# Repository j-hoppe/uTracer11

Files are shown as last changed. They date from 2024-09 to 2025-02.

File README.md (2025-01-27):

# uTracer11

„uTracer11“ (read: "micro-program-tracer for PDP-11") is a signal probe that is plugged into older UNIBUS PDP-11s.

The CPU state is visualized on a host PC via a graphical user interface (GUI)

It is primarily used for micro-stepping the CPU, as a function demo, repair tool, or for entertainment.

See: https://www.retrocmp.com/tools/utracer11

## Directory structure:
* common - C++ sources needed for M93X2 Arduino and GUI ... message protocol
* CSerialPort - C++ sources for RS232 interface Linux/Windows
* duktape - embedded JScript engine

* gui - main user interface, WxWidgets project Linux/Windows

* KM11.pcb - KiCad project for KM11 adapter probe

* M93X2probe.pcb - KiCad project for M93X2 probe PCB

* M93X2probe.pio - M93X2 probe Arduino firmware, PlatformI

* M93X2probe.pdp11data - PDP-11 code to be embedded into M93X2 BOOT logic

* Pdp11BusCycleDisas - source branch of UNIBUS traffic disassmebler for different PDP-11 CPUs

* pdp1134sim - case study for a micro machine based simulator, example is a 11/34 simple program loop

* resources - helper data files, scanned jpegs

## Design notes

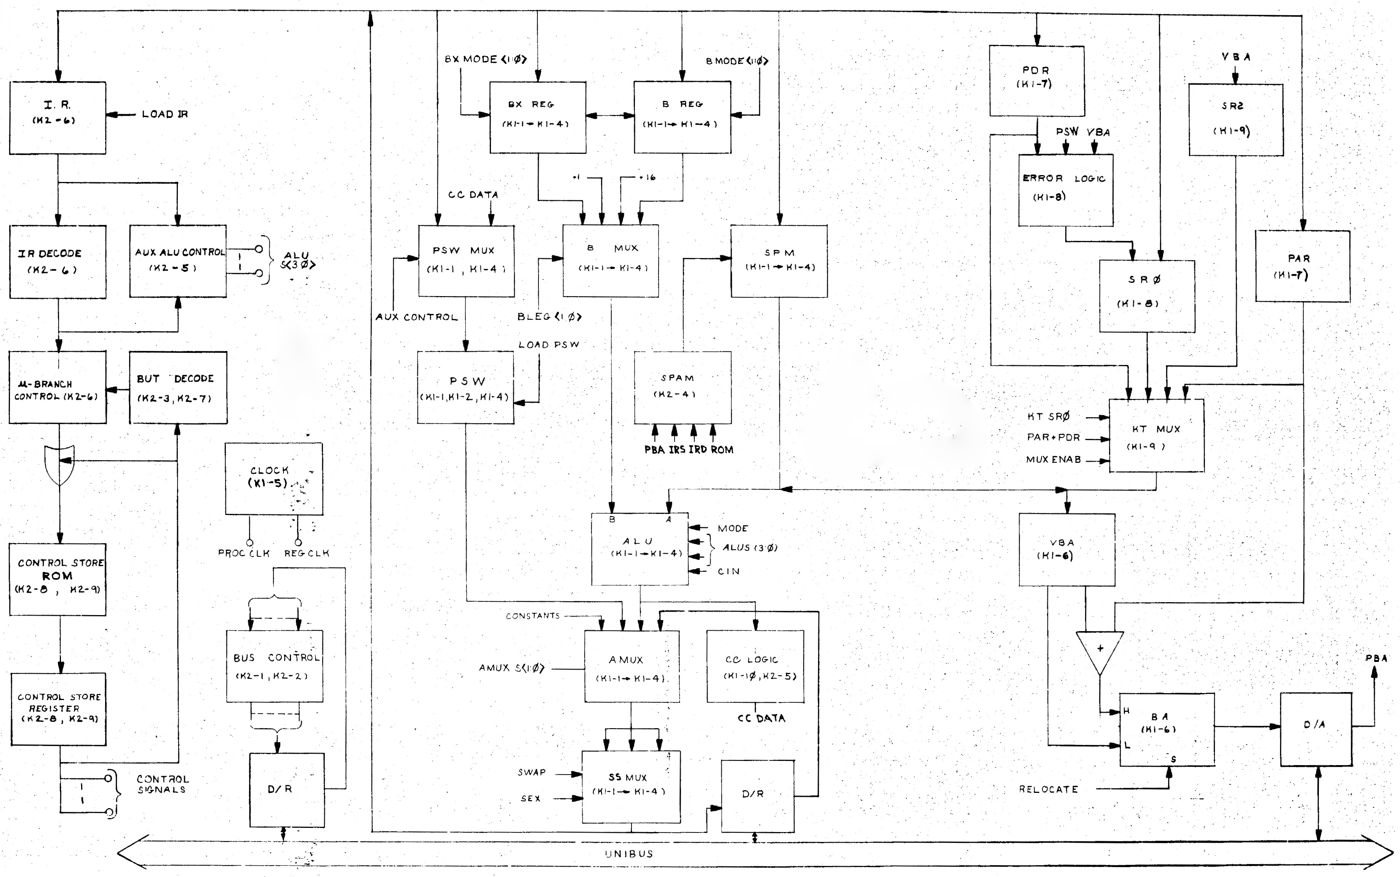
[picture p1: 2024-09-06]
resources/pdp1134/mp00082-datapath/MP00082-14.jpg

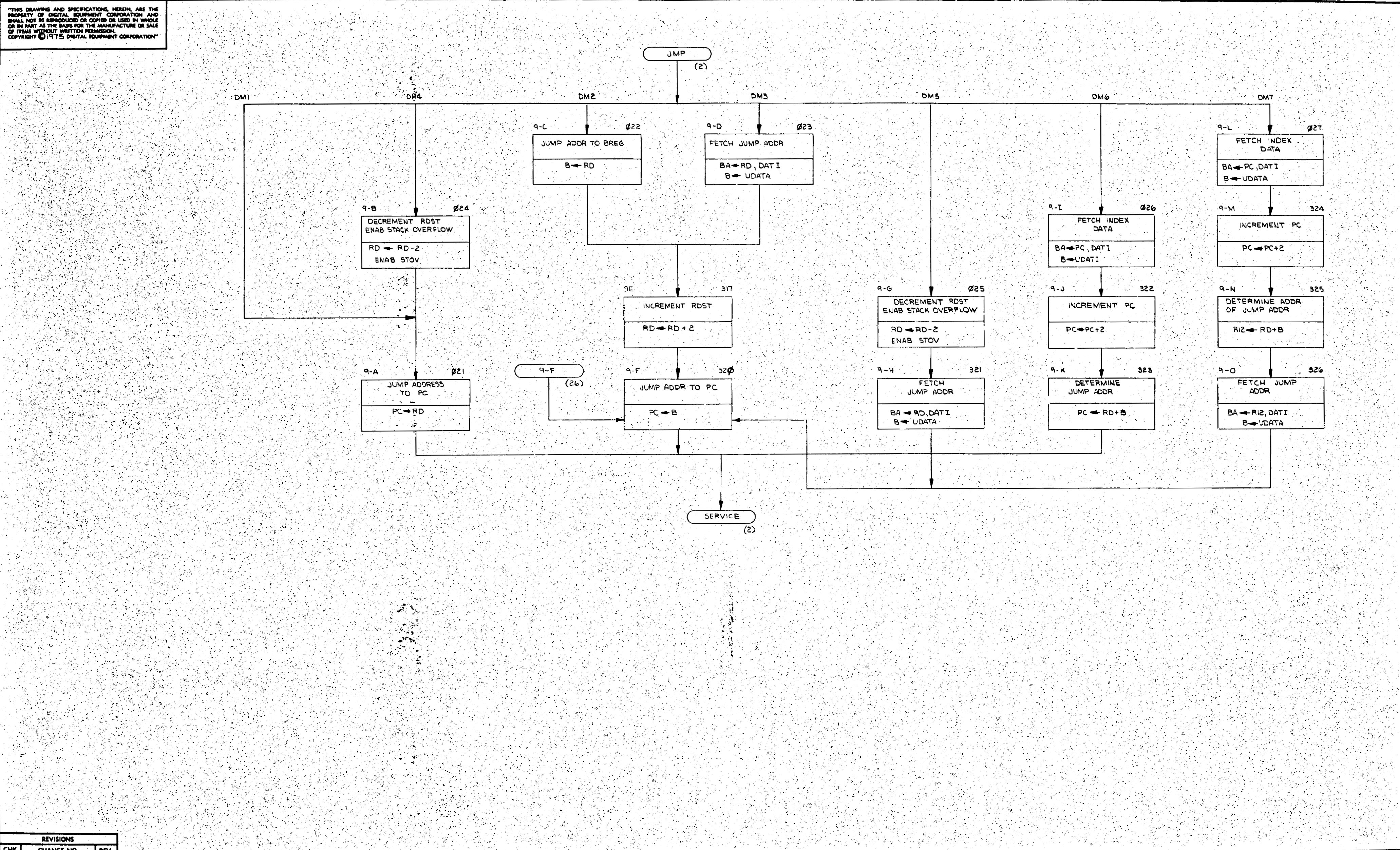
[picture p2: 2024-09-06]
resources/pdp1134/mp00082-uflow/MP00082-23.jpg

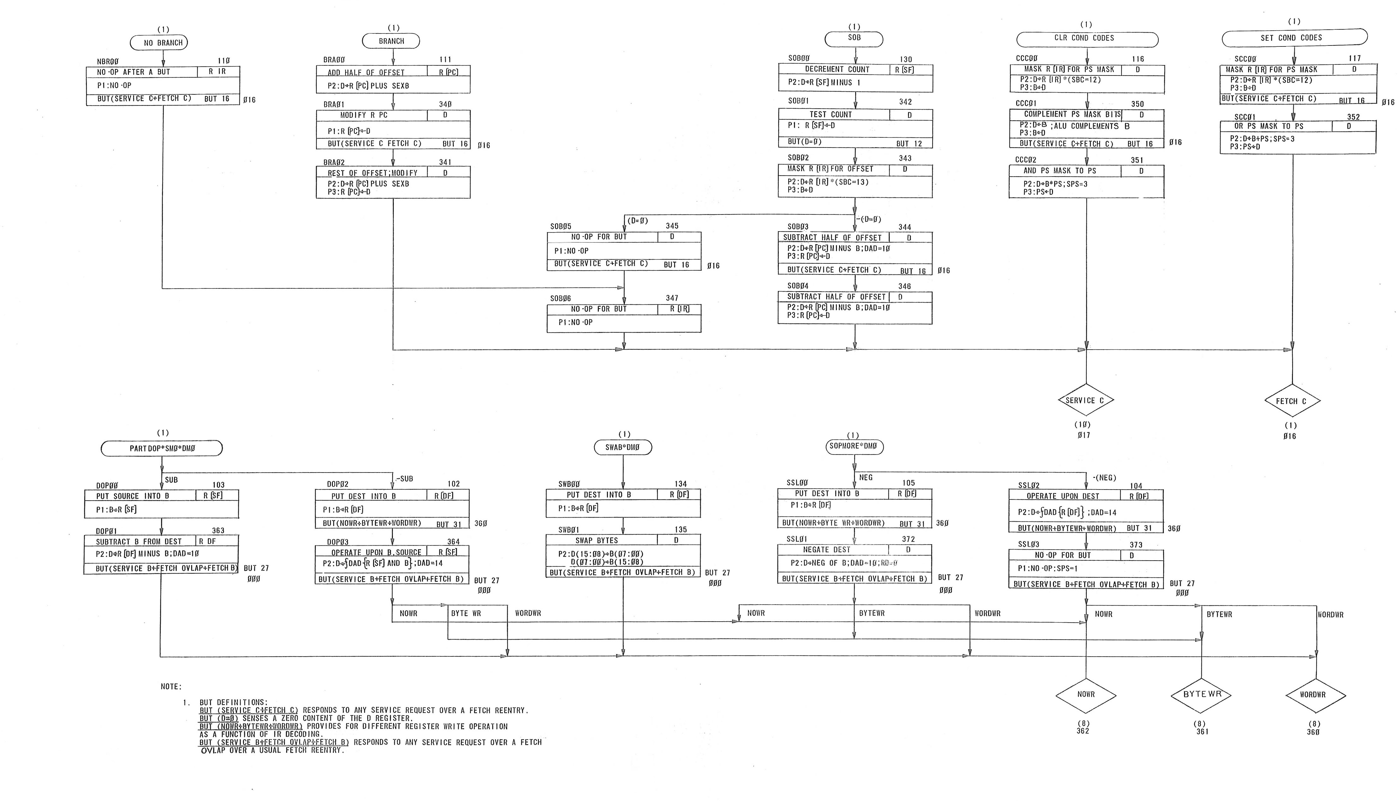
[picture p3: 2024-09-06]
resources/pdp1140/KD11-A_Processor_Flow_Diagrams/KD11-A_Processor_Flow_Diagrams-8.jpg

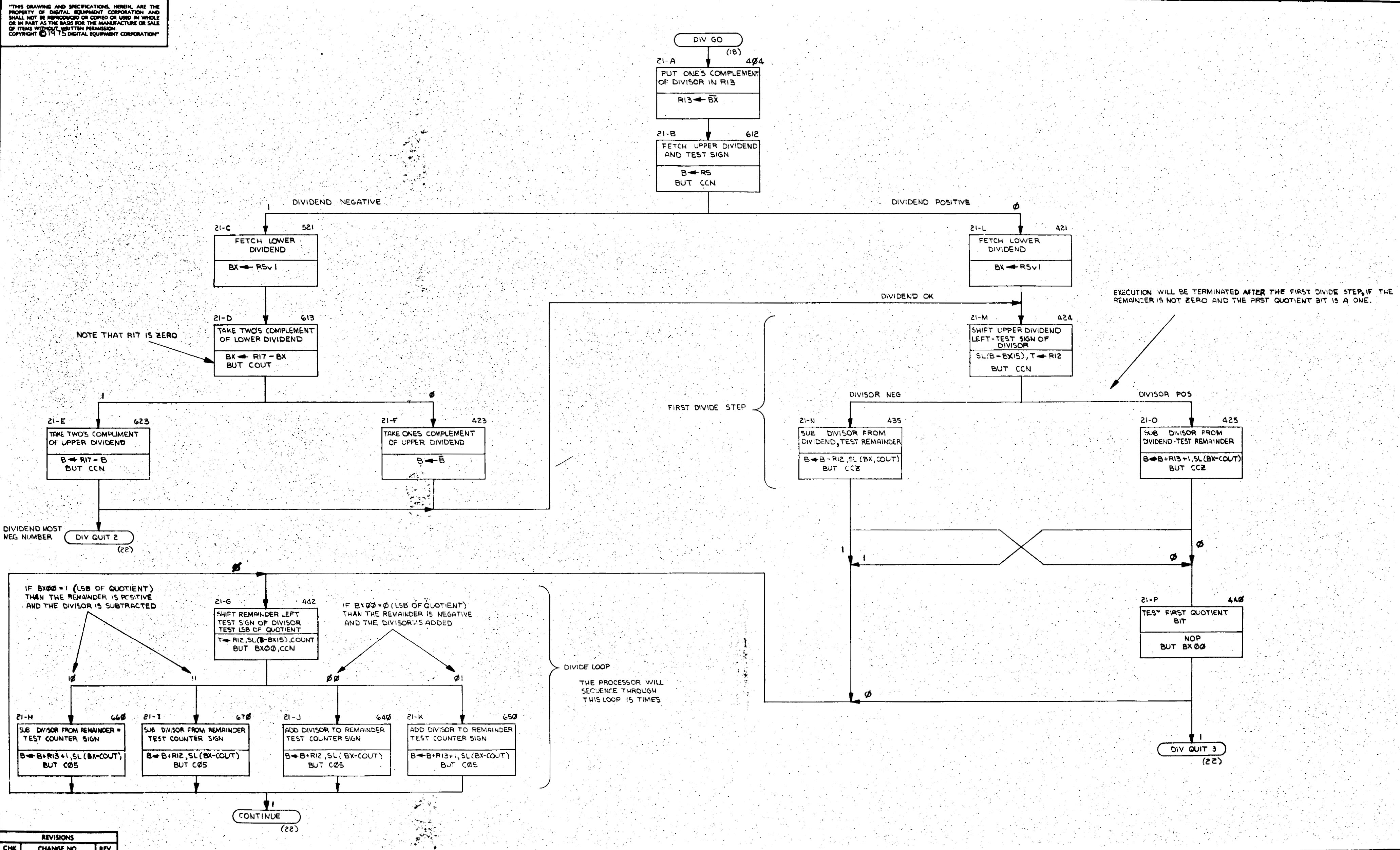
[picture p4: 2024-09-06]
resources/pdp1134/mp00082-uflow/MP00082-35.jpg

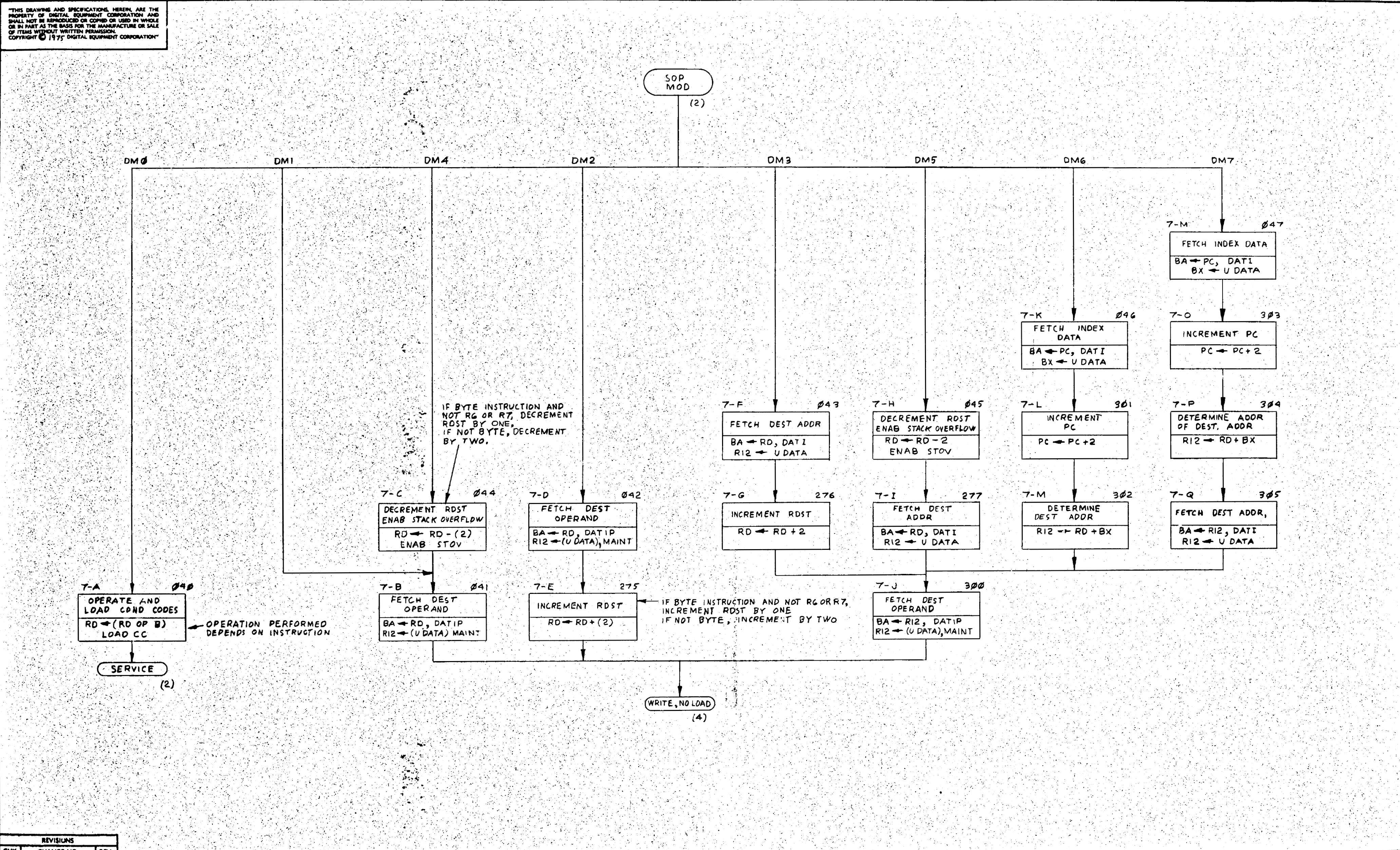
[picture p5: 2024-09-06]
resources/pdp1134/mp00082-uflow/MP00082-21.jpg

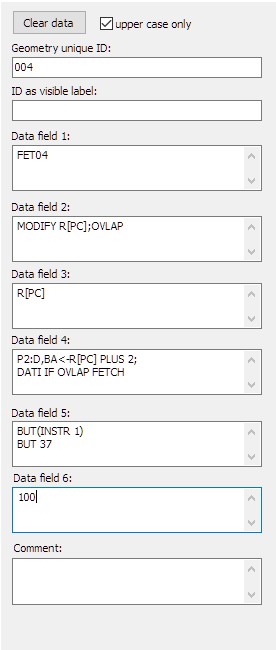
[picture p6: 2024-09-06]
resources/pdp1140/KD11-A_Processor_Flow_Diagrams/KD11-A_Processor_Flow_Diagrams-datafields-data.jpg

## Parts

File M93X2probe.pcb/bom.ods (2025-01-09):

Non-SMD parts for Diode ROM UNIBUS Base board
Count | 1
Ust | 1,19
Ref | Needed | Typ | Package | Info | Needed | At hand | Source | Nr | Preis | Anzahl | Preis total
 | 1 | Platine |  |  | 1 | 0 | jlcpcb |  | 8,00 € | 1 | 8,00 €
 | 1 | Shipping anteilig |  |  | 1 | 0 |  |  | 1,50 € | 1 | 1,50 €
 | 1 | Zoll anteilig |  |  | 1 | 0 |  |  | 0,00 € | 1 | 0,00 €
A1 | 1 | Arduino Nano Every |  |  | 1 | 0 | reichelt.de | ARD NANO EVE | 13,40 € | 1 | 13,40 €
C1-5,C7-8,C10-15,C21-36 | 29 | 100nF |  |  | 29 | 0 | reichelt.de | Z5U-5 100N | 0,08 € | 29 | 2,32 €
C6,C9 | 2 | 1nF |  |  | 2 | 0 | reichelt.de | KERKO 1,0N | 0,06 € | 2 | 0,12 € | x
C16 | 1 | 47uF |  | axial L=10, D=4.5 | 1 | 0 | reichelt.de | AX 47/16 | 0,31 € | 1 | 0,31 € | x
C17-20 | 4 | 1uF |  |  | 4 | 0 | reichelt.de | Z5U-5 1,0µ | 0,28 € | 4 | 1,12 € | x
D1,D2 | 2 | LED 3mm rot |  |  | 2 | 0 | reichelt.de | LED 3MM RT | 0,07 € | 2 | 0,14 € | x
D3-D6 | 4 | 1n4148 |  |  | 4 | 0 | reichelt.de | 1N 4148 | 0,02 € | 4 | 0,08 € | x
Jx | 2,2 | diverse pin header, 50er |  |  | 2,2 | 0 | reichelt.de | SL 1X50G 2,54 | 0,46 € | 2,2 | 1,01 € | x
J23,24 | 2 | 2x17 IDC |  | to KM11 | 2 | 0 | reichelt.de | WSL 34W | 0,32 € | 2 | 0,64 € | x
J18-22 | 5 | 2x5 IDC |  | RS232,KY11,M8266 | 5 | 0 | reichelt.de | WSL 10W | 0,13 € | 5 | 0,65 € | x
J30,31 | 2 | Flachstecker löt |  |  | 2 | 0 | reichelt.de | FS-PW-6,35 | 0,22 € | 2 | 0,44 € | x
JP1 | 1 | Jumper |  |  | 1 | 0 | reichelt.de | JUMPER 2,54 BL | 0,02 € | 1 | 0,02 €
R1-4 | 4 | 3.3K |  | I2C | 4 | 0 | reichelt.de | METALL 3,30K | 0,07 € | 4 | 0,28 € | x
R5,6 | 2 | 220 Ohm |  | LEDs | 2 | 0 | reichelt.de | METALL 220 | 0,07 € | 2 | 0,14 € | x
R7,8 | 2 | 390 Ohm |  | TERM | 2 | 0 | reichelt.de | METALL 390 | 0,07 € | 2 | 0,14 €
R9,10,12 | 3 | 1K |  | KY11 | 3 | 0 | reichelt.de | METALL 1,00K | 0,07 € | 3 | 0,21 € | x
RN1-2,RN5-6,RN9-10,RN13 | 7 | Rnet bussed 178 |  | UNIBUS terminators 178→180 | 7 | 0 | reichelt.de | SIL 9-8 180 | 0,15 € | 7 | 1,05 €
RN3-4,RN7-8,RN11-12,RN14 | 7 | Rnet bussed 383 |  | UNIBUS terminators 383→390 | 7 | 0 | reichelt.de | SIL 9-8 390 | 0,11 € | 7 | 0,77 € | x
R11 | 1 | 22k |  |  | 1 | 0 | reichelt.de | METALL 22,0K | 0,04 € | 1 | 0,04 € | x
 | 1,97 | 1x9 IC socket row precision, 64er |  |  | 1,97 | 0 | reichelt.de | SPL 64 | 1,30 € | 2 | 2,60 € | x
SW1 | 1 | Push button |  | Reset | 1 | 0 | reichelt.de | TASTER 3305 | 0,19 € | 1 | 0,19 € | x
SW2 | 1 | DIP Switch 6er Piano |  |  | 1 | 0 | reichelt.de | DP 06 | 0,31 € | 1 | 0,31 € | x
U1 | 1 | 74LS138 |  |  | 1 | 0 | reichelt.de | 74HCT 138 (https://www.reichelt.de/decoder-3-to-8-4-5--5-5-v-dil-16-74hct-138-p3318.html?&trstct=pos_0&nbc=1) | 0,63 € | 1 | 0,63 €
U2 | 1 | 74HCT30 |  |  | 1 | 0 | reichelt.de | 74LS30 | 1,10 € | 1 | 1,10 €
U3 | 1 | 8837 |  |  | 1 | 0 | ebay.de |  | 0,99 € | 1 | 0,99 €
U4 | 1 | 8881 |  |  | 1 | 0 | ebay.de |  | 0,99 € | 1 | 0,99 €
U5 | 1 | MAX232 |  |  | 1 | 0 | reichelt.de | MAX 232 DIP | 0,70 € | 1 | 0,70 €
U7 | 1 | 74LS86 |  |  | 1 | 0 | reichelt.de | 74HCT 86 | 0,67 € | 1 | 0,67 €
U6,U8-12,U15-16,U22-25 | 12 | MCP23017 |  |  | 12 | 0 | reichelt.de | MCP 23017-E/SP (https://www.reichelt.de/i-o-erweiterung-16bit-1-8-5v-seriell-i2c-dip-28-mcp-23017-e-sp-p140074.html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) | 1,80 € | 12 | 21,60 € | x
U13,U14 | 2 | 74HCT374 |  |  | 2 | 0 | reichelt.de | 74HCT374 | 0,76 € | 2 | 1,52 €
U17-21 | 5 | ULN2803 |  |  | 5 | 0 | reichelt.de | ULN2803A | 0,50 € | 5 | 2,50 €
U26 | 1 | 24LC1025-I/P |  |  | 1 | 0 | reichelt.de | 24LC1025-I/P | 2,25 € | 1 | 2,25 € | x
 | 1 | IC-Fassung 8 |  |  | 1 | 0 | reichelt.de | GS 8 | 0,04 € | 1 | 0,04 € | x
 | 3 | IC-Fassung 14 |  | 00,30,8881 | 3 |  | reichelt.de | GS 14 | 0,07 € | 3 | 0,21 € | x
 | 3 | IC-Fassung 16 |  | 138,8837,MAX232 | 3 | 0 | reichelt.de | GS 16 | 0,08 € | 3 | 0,24 € | x
 | 5 | IC-Fassung 18 |  | ULN2803 | 5 | 0 | reichelt.de | GS 18 | 0,07 € | 5 | 0,35 € | x
 | 2 | IC-Fassung 20 |  | 374 | 2 | 0 | reichelt.de | GS 20 | 0,09 € | 2 | 0,18 € | x
 | 12 | IC-Fassung 28 |  | MCP23017 | 12 | 0 | reichelt.de | GS 28-S | 0,14 € | 12 | 1,68 € | x
Nicht in BOM
 | 9 | 2x5 crimp |  | RS232,4*2KY11 | 9 | 0 | reichelt.de | PFL 10 | 0,11 € | 9 | 0,99 €
 | 1 | RS232 DSUB9 crimp |  |  | 1 | 0 | reichelt.de | D-SUB ST 09FB IS | 0,63 € | 1 | 0,63 €
 | 0,03 | 1m 10er Kabel, 30m Rolle |  | RS232, | 0,03 | 0 | reichelt.de | AWG 28-10G 30M (https://www.reichelt.de/flachbandkabel-awg28-10-pol-grau-30m-rolle-awg-28-10g-30m-p47622.html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) | 11,80 € | 0,03 | 0,39 €
 | 0,04 | 4*30cm 10er Kabel, 30m Rolle |  | 4*KY11 | 0,04 | 0 | reichelt.de | AWG 28-10G 30M (https://www.reichelt.de/flachbandkabel-awg28-10-pol-grau-30m-rolle-awg-28-10g-30m-p47622.html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) | 11,80 € | 0,04 | 0,47 €
 | 4 | 2 Kabel um KM11, 2x17 crimp |  | KM11 | 4 | 0 | reichelt.de | PFL 34 | 0,24 € | 4,00 | 0,96 €
 | 0,03 | 2*50cm, 34er→40er 30m Rolle |  | KM11 | 0,03 | 0 | reichelt.de | AWG 28-40G 30M | 44,90 € | 0,03 | 1,50 €
 | 1 | USB cable „Micro-USB-B“ zu Nano Every, 2m |  |  |  |  |  |  | 5,00 € | 0,00
Total parts pro Einkauf |  |  |  |  |  |  |  |  |  |  | 76,07 €
Total pro board |  | 76,07 €
Endkundenpreis |  | ?

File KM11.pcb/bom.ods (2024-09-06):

Non-SMD parts for Diode ROM UNIBUS Base board
Count | 2
Ust | 1,19
Ref | Needed | Typ | Package | Info | Needed | At hand | Source | Nr | Preis | Anzahl | Preis total
 | 1 | Platine |  | ENIG | 2 | 0 | jlcpcb |  | 5,00 € | 2 | 10,00 €
 | 1 | Shipping anteilig |  |  | 2 | 0 |  |  | 1,50 € | 2 | 3,00 €
 | 1 | Zoll anteilig |  |  | 2 | 0 |  |  | 0,00 € | 2 | 0,00 €
A1 | 1 | Arduino MEGA2560 PRO |  |  | 2 | 0 | reichelt.de | ARD MEGA2560 PRO | 19,10 € | 2 | 38,20 €
C1 | 1 | 47uF |  | axial L=10, D=4.5 | 2 | 0 | reichelt.de | AX 47/16 | 0,31 € | 2 | 0,62 €
C2,3,4,5 | 4 | 1uF |  |  | 8 |  | reichelt.de | Z5U-5 1,0µ | 0,28 € | 8 | 2,24 €
D1,D2 | 1 | LED 3mm |  |  | 2 | 1 | reichelt.de | LED 3MM RT | 0,07 € | 1 | 0,07 €
Jx | 2 | diverse pin header, 50er |  |  | 4 | 0 | reichelt.de | SL 1X50G 2,54 | 0,46 € | 4 | 1,84 €
J5 | 1 | 2x17 IDC |  | to uTracer | 2 | 0 | reichelt.de | WSL34W | 0,32 € | 2 | 0,64 €
J9 | 1 | 2x5 IDC |  | RS232 | 2 | 0 | reichelt.de | WSL10W | 0,13 € | 2 | 0,26 €
R1,R2 | 2 | 220 Ohm |  | LEDs | 4 | 0 | reichelt.de | METALL 220 | 0,07 € | 4 | 0,28 €
SW1 | 1 | Piano 4er |  |  | 2 | 0 | reichelt.de | DP 04 | 0,47 € | 2 | 0,94 €
SW2 | 1 | Push button |  |  | 2 | 0 | reichelt.de | TASTER 3305 | 0,19 € | 2 | 0,38 €
U1 | 1 | MAX232 |  |  | 2 | 0 | reichelt.de | MAX 232 DIP | 0,70 € | 2 | 1,40 €
 | 1 | Fassung |  |  | 2 | 0 | reichelt.de | GS16 | 0,08 € | 2 | 0,16 €
Nicht in BOM
 | 1 | RS232 2x5 crimp |  |  | 2 | 0 | reichelt.de | PFL10 | 0,11 € | 2 | 0,22 €
 | 1 | RS232 DSUB9 crimp |  |  | 2 | 0 | reichelt.de | D-SUB ST 09FB IS | 0,63 € | 2 | 1,26 €
 | 0,03 | 1m 10er Kabel, 30m ROlle |  |  | 0,07 | 0 | reichelt.de | AWG 28-10G 30M (https://www.reichelt.de/flachbandkabel-awg28-10-pol-grau-30m-rolle-awg-28-10g-30m-p47622.html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) | 11,80 € | 0,07 | 0,79 €
Total parts pro Einkauf |  |  |  |  |  |  |  |  |  |  | 62,30 €
Total pro board |  | 31,15 €

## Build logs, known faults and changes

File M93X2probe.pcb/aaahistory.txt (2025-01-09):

Modification to put in MUD slot / M9312
-----------------------------------------

Errata
-----------
Silk: J16 "PWR +5V=USB":
(connect wenn only USB cable connected, OR only +5V
disconnect when both +5V and USB.)

Silk: "KY11" -> "KY11-LB"

Share KY11 MSCP23017 with KM11
use additional inputs to monitor inputs from KY11-LB controller

2024-08
--------
Board name schanged to "M93X2" .. it is 9302 and 9312

DIP switch accessible from front.

FASTON und FASTONGND for external boot switch
(aus BlinkenBone 11/70 adapter übernehmen)
BOOTSWITCH 22k pullup
BOOTSWITCH RETURN über 1K an GND

EEPROM
1MBit = 128kx8 I2C eeprom drauf
Reichelt 24LC1025 I/P
A0,A1 = GND, A2 to vcc,
I2C addr 0 1010<block>00 =0xa0
MCP23017 have 0x20+x

DCLO U12.2 to Arduino Pin 11 D8 ex AUX0
ACLO U12.2 to Arduino Pin 12 D9 ex AUX1

M.U.D.: GND nur an AC2, AT1, BC2, BT1
Cut traces:
GND: AN1,AP1,AR1,AS1, AB2,AV2, BD1,BE1, BB2,BV2

M.U.D:
Solder bridges for BG*, NPG* (open for MUD!)
  -> 2x5 Jumperblock or 2x5 steckbare 0-Ohm SIP Leiste
BG4,5,6,7 = BE2, BB1, BA1, AV1
NPG = AU1

BBSY writeable
U4.13 an UNIBUS BBSY_L
U4.11,U4.12 an BBSY_OUT an MCP23017-0.3 GPB4 = pin 5

Silk label U3 8837
Silk: "µTracer11 M9302probe"

2024-03
------------
I2C pullups
minimal for 1MHz speed
DESIGNING-WITH-I2C-BUS-DEVICES.pdf
-> 1.7kohm, two parallel -> R1-R4 10KOhm-> 3.3kOhm
SDA is sunk by MEGA4809 and MCP23017. SCL only by MEGA.

Signal C1_OUT
U12.6 MCP0.3 GPB5 =>   U4.8,9
U4.10 -> "C1" pin header

U13, U14 74LS374
Inputs/Outputs vertauscht !!!

Signal SACK_OUT
U12.7 -> U4 5,6
U4.4 -> JP1.2

U7: 74ls00 -> 74ls86
Signal LATCH_DATA
MCP0.2 GPB7 -> U7B.4

Errata
Silk:
"C2" "100nF"
R9, R10: "1K"
LED D1, D2: Polarity

2024-02
-----------

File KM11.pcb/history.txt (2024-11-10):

2024-11:
----------

11/40
MCLK = out10
.------------------------------------------------.
|00 10 20 30 40 50 60                     flip   +.
|01 11 21 31 41 51 61      00  01         chip    |
|02 12 22 32 42 52 62      10  11         con-    |
|03 13 23 33 43 53 63                   nector   +´
`------------------------------------------------´

11/40:
                           --  MSTOP
                         MCLK  MCLK-ENAB

**** MCLK=out10 soll an flipchip U1 gehen! ****
**** out01 MSTOP soll gehen an B2 ****

TRACER_OUT10 ->TRACER_OUT10_L
PDP_out10 -> PDP_out10_L

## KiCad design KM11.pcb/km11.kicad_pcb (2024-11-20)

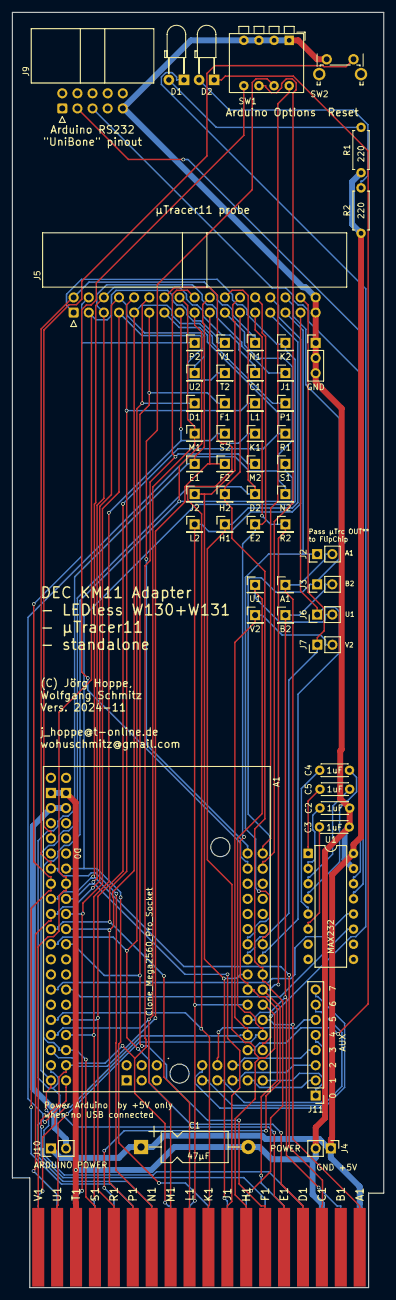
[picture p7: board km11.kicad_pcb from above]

Board: 2 copper layers, 62.4 x 214.1 mm, 56 parts (0 on the bottom side), 66 nets.

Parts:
A1: Clone_Mega2560_Pro_Socket
C1: 47µF; CP_Axial_L11.0mm_D5.0mm_P18.00mm_Horizontal
C2, C3, C4, C5: 1uF; C_Disc_D4.3mm_W1.9mm_P5.00mm
D1: LED1; LED_D3.0mm_Horizontal_O3.81mm_Z2.0mm
D2: LED2; LED_D3.0mm_Horizontal_O3.81mm_Z2.0mm
J1: PDP11 FlipChipSlot2x18; dec-conn-single-ht-pins-only
J2: PASS_A1; PinHeader_1x02_P2.54mm_Vertical
J3: PASS_B2; PinHeader_1x02_P2.54mm_Vertical
J4: POWER; PinHeader_1x02_P2.54mm_Vertical
J5: µTracer11 2x17 IDC; IDC-Header_2x17_P2.54mm_Horizontal
J6: PASS_U1; PinHeader_1x02_P2.54mm_Vertical
J7: PASS_V2; PinHeader_1x02_P2.54mm_Vertical
J8: GND; PinHeader_1x03_P2.54mm_Vertical
J9: UART1_RS232_Schneid-Klemm_2x5; IDC-Header_2x05_P2.54mm_Horizontal
J10: ARDUINO POWER; PinHeader_1x02_P2.54mm_Vertical
J11: AUX; PinHeader_1x08_P2.54mm_Vertical
R1, R2: 220; R_Axial_DIN0207_L6.3mm_D2.5mm_P7.62mm_Horizontal
SW1: Option; SW_DIP_SPSTx04_Piano_CTS_Series194-4MSTN_W7.62mm_P2.54mm
SW2: Reset; SW_Tactile_SPST_Angled_PTS645Vx58-2LFS
TP1: R2; PinHeader_1x01_P2.54mm_Vertical
TP2: N2; PinHeader_1x01_P2.54mm_Vertical
TP3: S1; PinHeader_1x01_P2.54mm_Vertical
TP4: R1; PinHeader_1x01_P2.54mm_Vertical
TP5: P1; PinHeader_1x01_P2.54mm_Vertical
TP6: J1; PinHeader_1x01_P2.54mm_Vertical
TP7: K2; PinHeader_1x01_P2.54mm_Vertical
TP8: E2; PinHeader_1x01_P2.54mm_Vertical
TP9: D2; PinHeader_1x01_P2.54mm_Vertical
TP10: M2; PinHeader_1x01_P2.54mm_Vertical
TP11: K1; PinHeader_1x01_P2.54mm_Vertical
TP12: L1; PinHeader_1x01_P2.54mm_Vertical
TP13: C1; PinHeader_1x01_P2.54mm_Vertical
TP14: N1; PinHeader_1x01_P2.54mm_Vertical
TP15: H1; PinHeader_1x01_P2.54mm_Vertical
TP16: H2; PinHeader_1x01_P2.54mm_Vertical
TP17: F2; PinHeader_1x01_P2.54mm_Vertical
TP18: S2; PinHeader_1x01_P2.54mm_Vertical
TP19: F1; PinHeader_1x01_P2.54mm_Vertical
TP20: T2; PinHeader_1x01_P2.54mm_Vertical
TP21: V1; PinHeader_1x01_P2.54mm_Vertical
TP22: L2; PinHeader_1x01_P2.54mm_Vertical
TP23: J2; PinHeader_1x01_P2.54mm_Vertical
TP24: E1; PinHeader_1x01_P2.54mm_Vertical
TP25: M1; PinHeader_1x01_P2.54mm_Vertical
TP26: D1; PinHeader_1x01_P2.54mm_Vertical
TP27: U2; PinHeader_1x01_P2.54mm_Vertical
TP28: P2; PinHeader_1x01_P2.54mm_Vertical
TP29: A1; PinHeader_1x01_P2.54mm_Vertical
TP30: B2; PinHeader_1x01_P2.54mm_Vertical
TP31: U1; PinHeader_1x01_P2.54mm_Vertical
TP32: V2; PinHeader_1x01_P2.54mm_Vertical
U1: MAX232; DIP-16_W7.62mm

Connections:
5V: C1.1, J1.A2, J4.1, J10.1, R1.1, R2.1, U1.16 (VCC)
/arduino/ARDUINO_5V: A1.5V1 (5V), A1.5V3 (5V), J10.2
/arduino/AUX0: A1.D46, J11.1
/arduino/AUX1: A1.D47, J11.2
/arduino/AUX2: A1.D48, J11.3
/arduino/AUX3: A1.D49, J11.4
/arduino/AUX4: A1.D50 (D50_MISO), J11.5
/arduino/AUX5: A1.D51 (D51_MOSI), J11.6
/arduino/AUX6: A1.D52 (D52_SCK), J11.7
/arduino/AUX7: A1.D53 (D53_CS), J11.8
/arduino/LED1: A1.D42, D1.1 (K)
/arduino/LED2: A1.D43, D2.1 (K)
/arduino/RS232-RX: A1.D19 (D19/RX1), U1.12 (R1OUT)
/arduino/RS232-TX: A1.D18 (D18/TX1), U1.11 (T1IN)
C1: A1.D7, J1.C1, J5.6, TP13.1
D1: A1.D13, J1.D1, J5.12, TP26.1
D2: A1.D31, J1.D2, J5.22, TP9.1
E1: A1.D29, J1.E1, J5.20, TP24.1
E2: A1.D35, J1.E2, J5.26, TP8.1
F1: A1.D12, J1.F1, J5.11, TP19.1
F2: A1.D28, J1.F2, J5.19, TP17.1
GND: A1.GND1 (GND), A1.GND2 (GND), C1.2, C2.2, C3.2, J1.C2, J1.T1, J4.2, J5.33, J5.34, J8.1, J8.2, J8.3, J9.9 (GND), SW1.1, SW1.2, SW1.3, SW1.4, SW2.1, U1.15 (GND)
H1: A1.D36, J1.H1, J5.27, TP15.1
H2: A1.D32, J1.H2, J5.23, TP16.1
J1: A1.D6, J1.J1, J5.5, TP6.1
J2: A1.D33, J1.J2, J5.24, TP23.1
K1: A1.D23, J1.K1, J5.14, TP11.1
K2: A1.D2 (D2_INT0), J1.K2, J5.1, TP7.1
L1: A1.D11, J1.L1, J5.10, TP12.1
L2: A1.D37, J1.L2, J5.28, TP22.1
M1: A1.D25, J1.M1, J5.16, TP25.1
M2: A1.D27, J1.M2, J5.18, TP10.1
N1: A1.D3 (D3_INT1), J1.N1, J5.2, TP14.1
N2: A1.D30, J1.N2, J5.21, TP2.1
unnamed: A1.A0, SW1.8
unnamed: A1.A1, SW1.7
unnamed: A1.A2, SW1.6
unnamed: A1.A3, SW1.5
unnamed: A1.RST1 (RESET), SW2.2
unnamed: D1.2 (A), R1.2
unnamed: D2.2 (A), R2.2
unnamed: J9.3 (RXD), U1.13 (R1IN)
unnamed: J9.5 (TXD), U1.14 (T1OUT)
unnamed: C5.1, U1.1 (C1+)
unnamed: C5.2, U1.3 (C1-)
unnamed: C4.1, U1.4 (C2+)
unnamed: C4.2, U1.5 (C2-)
unnamed: C2.1, U1.2 (VS+)
unnamed: C3.1, U1.6 (VS-)
P1: A1.D10, J1.P1, J5.9, TP5.1
P2: A1.D5, J1.P2, J5.4, TP28.1
PDP_A1_L: A1.D38, J1.A1, J2.2, TP29.1
PDP_B2_L: A1.D39, J1.B2, J3.2, TP30.1
PDP_U1_L: A1.D40, J1.U1, J6.2, TP31.1
PDP_V2_L: A1.D41, J1.V2, J7.2, TP32.1
R1: A1.D22, J1.R1, J5.13, TP4.1
R2: A1.D34, J1.R2, J5.25, TP1.1
S1: A1.D26, J1.S1, J5.17, TP3.1
S2: A1.D24, J1.S2, J5.15, TP18.1
T2: A1.D8, J1.T2, J5.7, TP20.1
TRACER_A1_L: A1.A12, J2.1, J5.29
TRACER_B2_L: A1.A13, J3.1, J5.30
TRACER_U1_L: A1.A14, J5.31, J6.1
TRACER_V2_L: A1.A15, J5.32, J7.1
U2: A1.D9, J1.U2, J5.8, TP27.1
V1: A1.D4, J1.V1, J5.3, TP21.1

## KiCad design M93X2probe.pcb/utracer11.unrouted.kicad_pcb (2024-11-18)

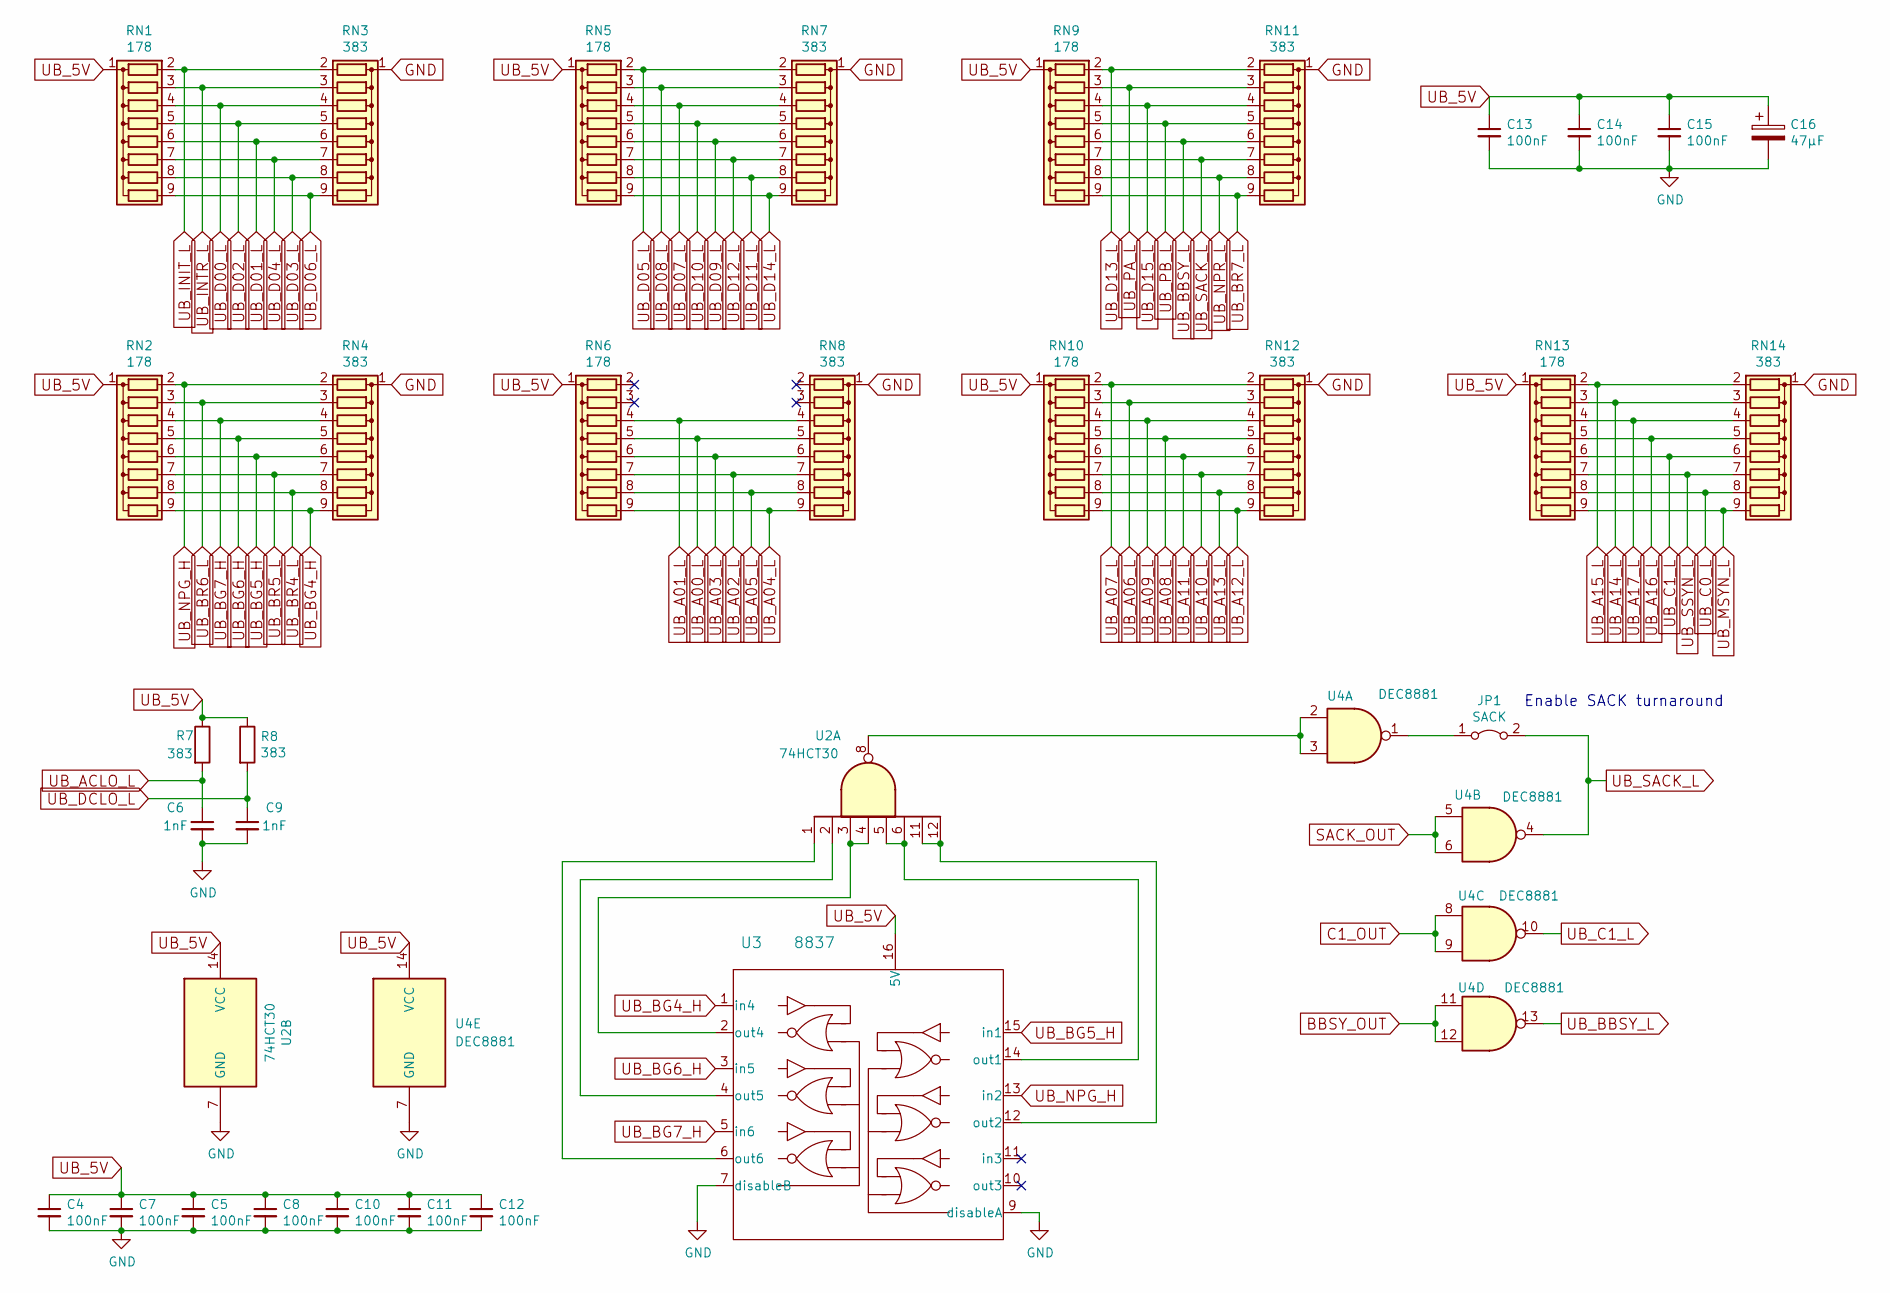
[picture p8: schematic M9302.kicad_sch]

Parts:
C4, C5, C7, C8, C10, C11, C12, C13, C14, C15: 100nF; C_Disc_D4.3mm_W1.9mm_P5.00mm; LCSC C49678
C6, C9: 1nF; C_Disc_D4.3mm_W1.9mm_P5.00mm; LCSC C46653
C16: 47µF; CP_Axial_L11.0mm_D5.0mm_P18.00mm_Horizontal
JP1: SACK; PinHeader_1x02_P2.54mm_Vertical
R7, R8: 383; R_Axial_DIN0207_L6.3mm_D2.5mm_P2.54mm_Vertical; LCSC C17655
RN1, RN2, RN5, RN6, RN9, RN10, RN13: 178; R_Array_SIP9
RN3, RN4, RN7, RN8, RN11, RN12, RN14: 383; R_Array_SIP9
U2: 74HCT30; DIP-14_W7.62mm; LCSC C2865549
U3: 8837; DIP-16_W7.62mm
U4: DEC8881; DIP-14_W7.62mm

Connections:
BBSY_OUT: U4.11, U4.12; also elsewhere on the board
C1_OUT: U4.8, U4.9; also elsewhere on the board
GND: C4.2, C5.2, C6.2, C7.2, C8.2, C9.2, C10.2, C11.2, C12.2, C13.2, C14.2, C15.2, C16.2, RN3.1 (common), RN4.1 (common), RN7.1 (common), RN8.1 (common), RN11.1 (common), RN12.1 (common), RN14.1 (common), U2.7 (GND), U3.7 (disableB), U3.8 (GND), U3.9 (disableA), U4.7 (GND); also elsewhere on the board
unnamed: JP1.1 (A), U4.1
unnamed: U2.8, U4.2, U4.3
unnamed: U2.5, U2.6, U3.14 (out1)
unnamed: U2.11, U2.12, U3.12 (out2)
unnamed: U2.3, U2.4, U3.2 (out4)
unnamed: U2.2, U3.4 (out5)
unnamed: U2.1, U3.6 (out6)
SACK_OUT: U4.5, U4.6; also elsewhere on the board
UB_5V: C4.1, C5.1, C7.1, C8.1, C10.1, C11.1, C12.1, C13.1, C14.1, C15.1, C16.1, R7.1, R8.1, RN1.1 (common), RN2.1 (common), RN5.1 (common), RN6.1 (common), RN9.1 (common), RN10.1 (common), RN13.1 (common), U2.14 (VCC), U3.16 (5V), U4.14 (VCC); also elsewhere on the board
UB_A00_L: RN6.5 (R4), RN8.5 (R4); also elsewhere on the board
UB_A01_L: RN6.4 (R3), RN8.4 (R3); also elsewhere on the board
UB_A02_L: RN6.7 (R6), RN8.7 (R6); also elsewhere on the board
UB_A03_L: RN6.6 (R5), RN8.6 (R5); also elsewhere on the board
UB_A04_L: RN6.9 (R8), RN8.9 (R8); also elsewhere on the board
UB_A05_L: RN6.8 (R7), RN8.8 (R7); also elsewhere on the board
UB_A06_L: RN10.3 (R2), RN12.3 (R2); also elsewhere on the board
UB_A07_L: RN10.2 (R1), RN12.2 (R1); also elsewhere on the board
UB_A08_L: RN10.5 (R4), RN12.5 (R4); also elsewhere on the board
UB_A09_L: RN10.4 (R3), RN12.4 (R3); also elsewhere on the board
UB_A10_L: RN10.7 (R6), RN12.7 (R6); also elsewhere on the board
UB_A11_L: RN10.6 (R5), RN12.6 (R5); also elsewhere on the board
UB_A12_L: RN10.9 (R8), RN12.9 (R8); also elsewhere on the board
UB_A13_L: RN10.8 (R7), RN12.8 (R7); also elsewhere on the board
UB_A14_L: RN13.3 (R2), RN14.3 (R2); also elsewhere on the board
UB_A15_L: RN13.2 (R1), RN14.2 (R1); also elsewhere on the board
UB_A16_L: RN13.5 (R4), RN14.5 (R4); also elsewhere on the board
UB_A17_L: RN13.4 (R3), RN14.4 (R3); also elsewhere on the board
UB_ACLO_L: C6.1, R7.2; also elsewhere on the board
UB_BBSY_L: RN9.6 (R5), RN11.6 (R5), U4.13; also elsewhere on the board
UB_BG4_H: RN2.9 (R8), RN4.9 (R8), U3.1 (in4); also elsewhere on the board
UB_BG5_H: RN2.6 (R5), RN4.6 (R5), U3.15 (in1); also elsewhere on the board
UB_BG6_H: RN2.5 (R4), RN4.5 (R4), U3.3 (in5); also elsewhere on the board
UB_BG7_H: RN2.4 (R3), RN4.4 (R3), U3.5 (in6); also elsewhere on the board
UB_BR4_L: RN2.8 (R7), RN4.8 (R7); also elsewhere on the board
UB_BR5_L: RN2.7 (R6), RN4.7 (R6); also elsewhere on the board
UB_BR6_L: RN2.3 (R2), RN4.3 (R2); also elsewhere on the board
UB_BR7_L: RN9.9 (R8), RN11.9 (R8); also elsewhere on the board
UB_C0_L: RN13.8 (R7), RN14.8 (R7); also elsewhere on the board
UB_C1_L: RN13.6 (R5), RN14.6 (R5), U4.10; also elsewhere on the board
UB_D00_L: RN1.4 (R3), RN3.4 (R3); also elsewhere on the board
UB_D01_L: RN1.6 (R5), RN3.6 (R5); also elsewhere on the board
UB_D02_L: RN1.5 (R4), RN3.5 (R4); also elsewhere on the board
UB_D03_L: RN1.8 (R7), RN3.8 (R7); also elsewhere on the board
UB_D04_L: RN1.7 (R6), RN3.7 (R6); also elsewhere on the board
UB_D05_L: RN5.2 (R1), RN7.2 (R1); also elsewhere on the board
UB_D06_L: RN1.9 (R8), RN3.9 (R8); also elsewhere on the board
UB_D07_L: RN5.4 (R3), RN7.4 (R3); also elsewhere on the board
UB_D08_L: RN5.3 (R2), RN7.3 (R2); also elsewhere on the board
UB_D09_L: RN5.6 (R5), RN7.6 (R5); also elsewhere on the board
UB_D10_L: RN5.5 (R4), RN7.5 (R4); also elsewhere on the board
UB_D11_L: RN5.8 (R7), RN7.8 (R7); also elsewhere on the board
UB_D12_L: RN5.7 (R6), RN7.7 (R6); also elsewhere on the board
UB_D13_L: RN9.2 (R1), RN11.2 (R1); also elsewhere on the board
UB_D14_L: RN5.9 (R8), RN7.9 (R8); also elsewhere on the board
UB_D15_L: RN9.4 (R3), RN11.4 (R3); also elsewhere on the board
UB_DCLO_L: C9.1, R8.2; also elsewhere on the board
UB_INIT_L: RN1.2 (R1), RN3.2 (R1); also elsewhere on the board
UB_INTR_L: RN1.3 (R2), RN3.3 (R2); also elsewhere on the board
UB_MSYN_L: RN13.9 (R8), RN14.9 (R8); also elsewhere on the board
UB_NPG_H: RN2.2 (R1), RN4.2 (R1), U3.13 (in2); also elsewhere on the board
UB_NPR_L: RN9.8 (R7), RN11.8 (R7); also elsewhere on the board
UB_PA_L: RN9.3 (R2), RN11.3 (R2); also elsewhere on the board
UB_PB_L: RN9.5 (R4), RN11.5 (R4); also elsewhere on the board
UB_SACK_L: JP1.2 (B), RN9.7 (R6), RN11.7 (R6), U4.4; also elsewhere on the board
UB_SSYN_L: RN13.7 (R6), RN14.7 (R6); also elsewhere on the board

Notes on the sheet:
Enable SACK turnaround

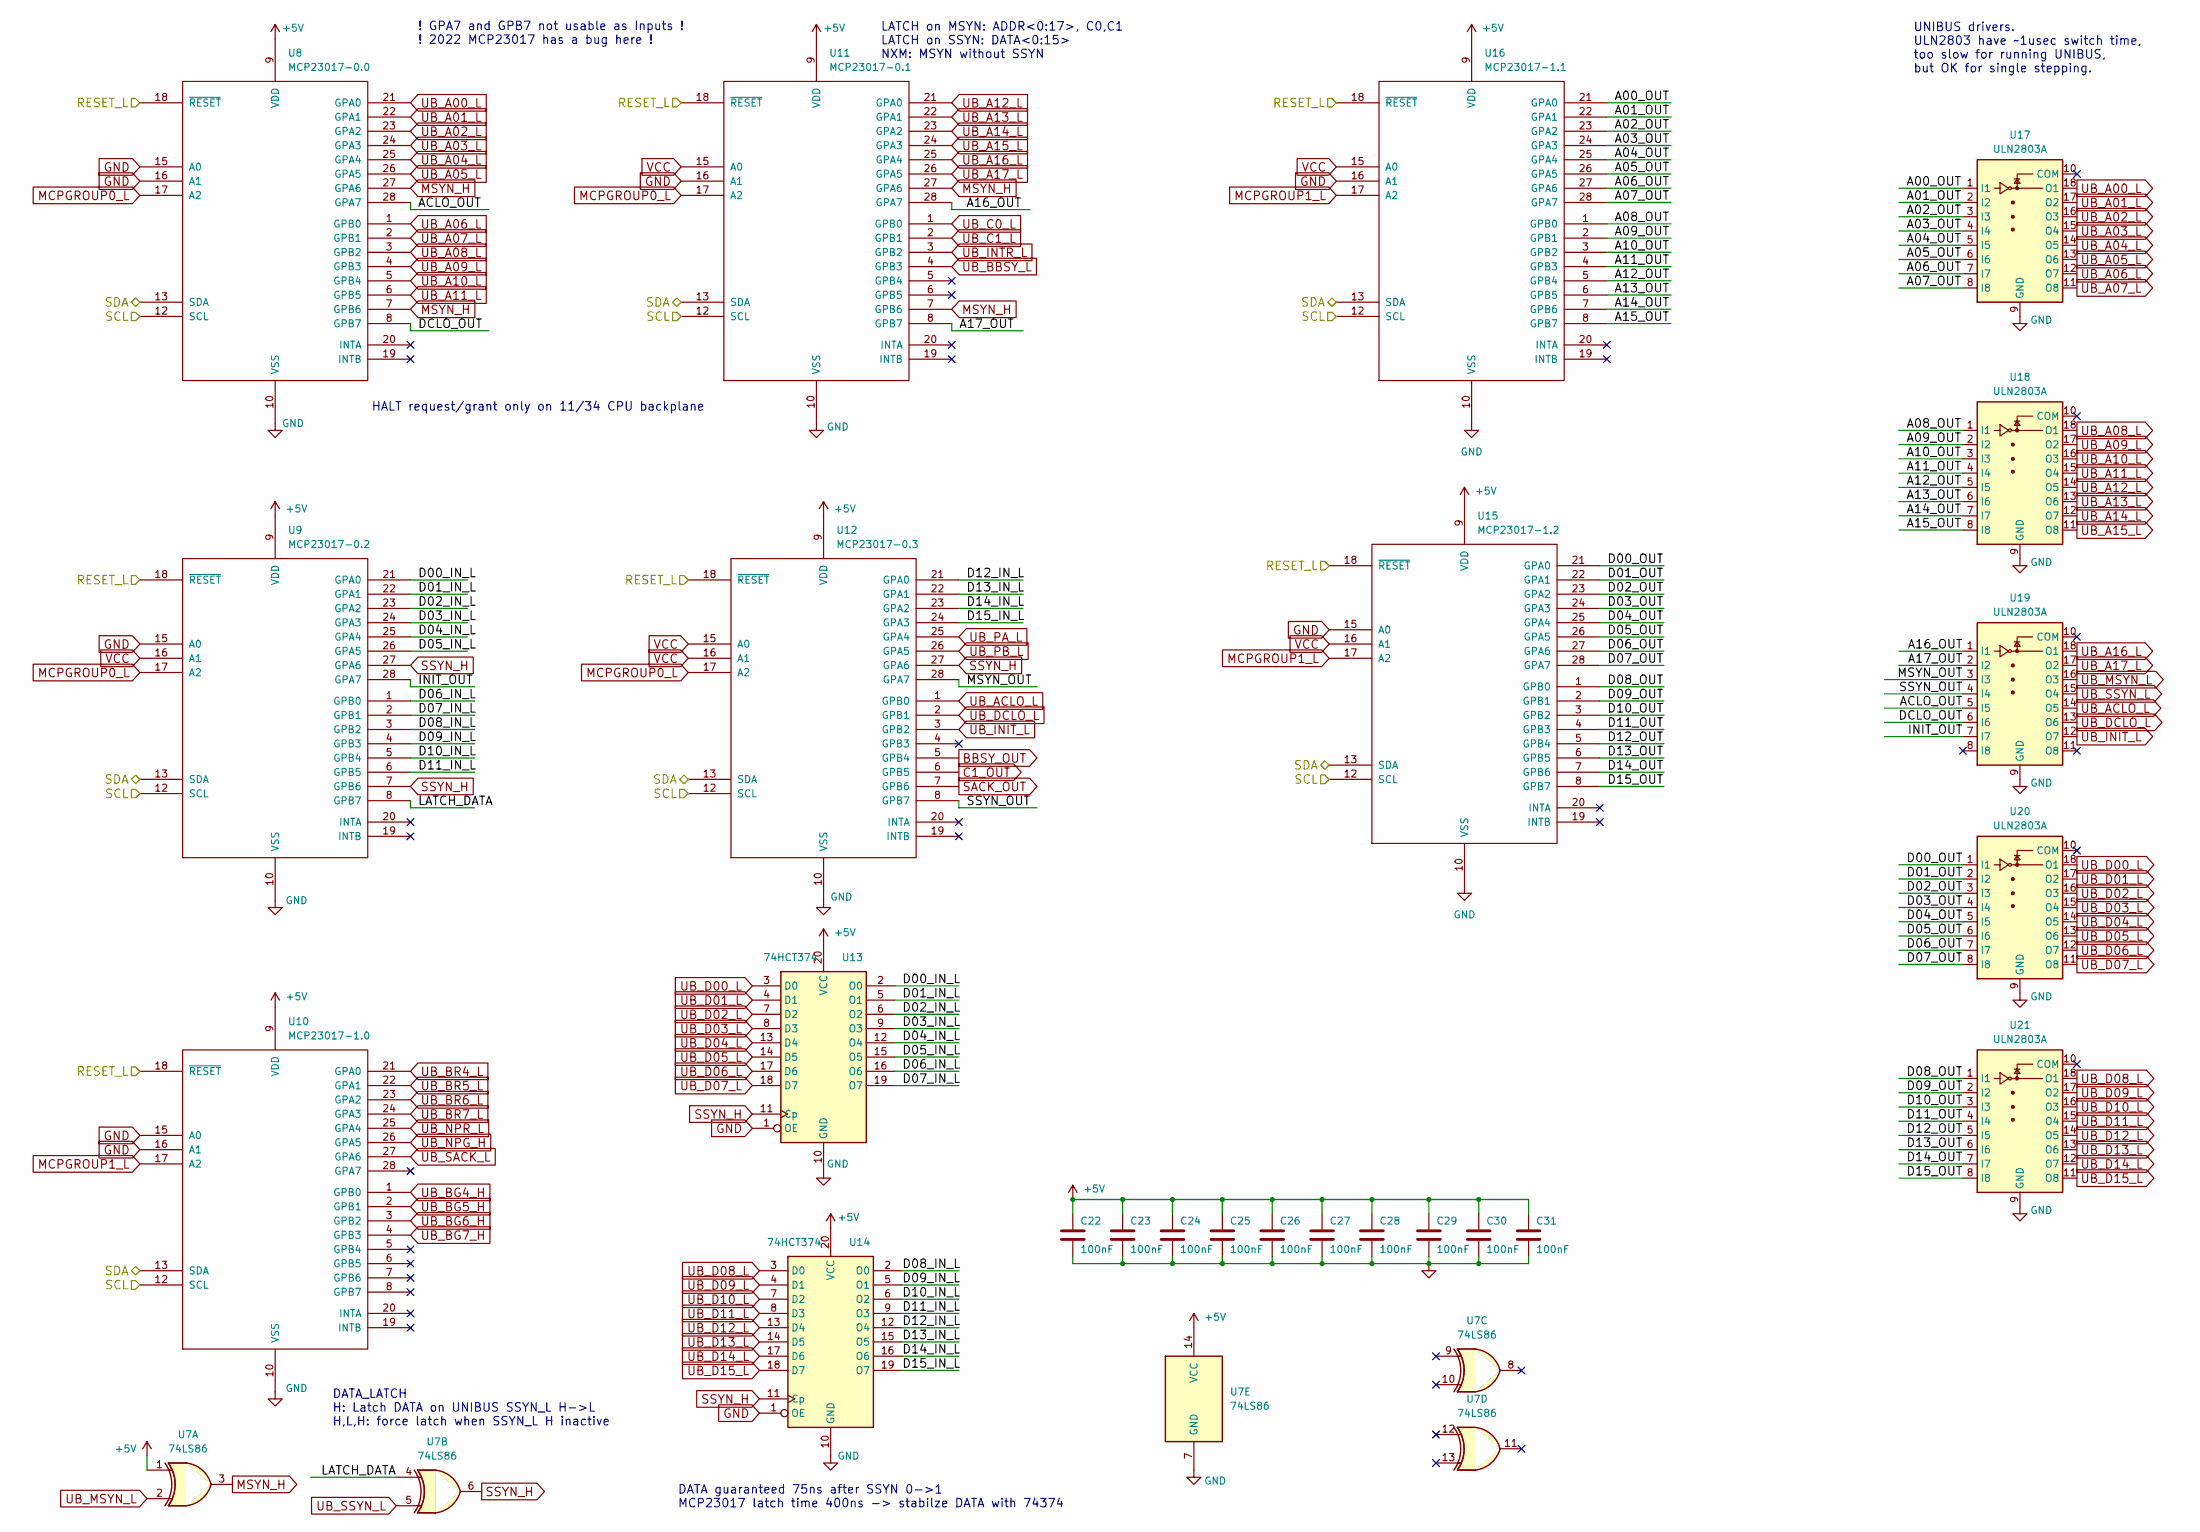
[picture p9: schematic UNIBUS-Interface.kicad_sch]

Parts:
C22, C23, C24, C25, C26, C27, C28, C29, C30, C31: 100nF; C_Disc_D4.3mm_W1.9mm_P5.00mm
U7: 74LS86; DIP-14_W7.62mm
U8: MCP23017-0.0; DIP-28_W7.62mm
U9: MCP23017-0.2; DIP-28_W7.62mm
U10: MCP23017-1.0; DIP-28_W7.62mm
U11: MCP23017-0.1; DIP-28_W7.62mm
U12: MCP23017-0.3; DIP-28_W7.62mm
U13, U14: 74HCT374; DIP-20_W7.62mm
U15: MCP23017-1.2; DIP-28_W7.62mm
U16: MCP23017-1.1; DIP-28_W7.62mm
U17, U18, U19, U20, U21: ULN2803A; DIP-18_W7.62mm

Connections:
/MCP_RESET_L: U8.18 (~RESET), U9.18 (~RESET), U10.18 (~RESET), U11.18 (~RESET), U12.18 (~RESET), U15.18 (~RESET), U16.18 (~RESET); also elsewhere on the board
/SCL: U8.12 (SCL), U9.12 (SCL), U10.12 (SCL), U11.12 (SCL), U12.12 (SCL), U15.12 (SCL), U16.12 (SCL); also elsewhere on the board
/SDA: U8.13 (SDA), U9.13 (SDA), U10.13 (SDA), U11.13 (SDA), U12.13 (SDA), U15.13 (SDA), U16.13 (SDA); also elsewhere on the board
/UNIBUS-Interface/A00_OUT: U16.21 (GPA0), U17.1 (I1)
/UNIBUS-Interface/A01_OUT: U16.22 (GPA1), U17.2 (I2)
/UNIBUS-Interface/A02_OUT: U16.23 (GPA2), U17.3 (I3)
/UNIBUS-Interface/A03_OUT: U16.24 (GPA3), U17.4 (I4)
/UNIBUS-Interface/A04_OUT: U16.25 (GPA4), U17.5 (I5)
/UNIBUS-Interface/A05_OUT: U16.26 (GPA5), U17.6 (I6)
/UNIBUS-Interface/A06_OUT: U16.27 (GPA6), U17.7 (I7)
/UNIBUS-Interface/A07_OUT: U16.28 (GPA7), U17.8 (I8)
/UNIBUS-Interface/A08_OUT: U16.1 (GPB0), U18.1 (I1)
/UNIBUS-Interface/A09_OUT: U16.2 (GPB1), U18.2 (I2)
/UNIBUS-Interface/A10_OUT: U16.3 (GPB2), U18.3 (I3)
/UNIBUS-Interface/A11_OUT: U16.4 (GPB3), U18.4 (I4)
/UNIBUS-Interface/A12_OUT: U16.5 (GPB4), U18.5 (I5)
/UNIBUS-Interface/A13_OUT: U16.6 (GPB5), U18.6 (I6)
/UNIBUS-Interface/A14_OUT: U16.7 (GPB6), U18.7 (I7)
/UNIBUS-Interface/A15_OUT: U16.8 (GPB7), U18.8 (I8)
/UNIBUS-Interface/A16_OUT: U11.28 (GPA7), U19.1 (I1)
/UNIBUS-Interface/A17_OUT: U11.8 (GPB7), U19.2 (I2)
/UNIBUS-Interface/ACLO_OUT: U8.28 (GPA7), U19.5 (I5)
/UNIBUS-Interface/D00_IN_L: U9.21 (GPA0), U13.2 (O0)
/UNIBUS-Interface/D00_OUT: U15.21 (GPA0), U20.1 (I1)
/UNIBUS-Interface/D01_IN_L: U9.22 (GPA1), U13.5 (O1)
/UNIBUS-Interface/D01_OUT: U15.22 (GPA1), U20.2 (I2)
/UNIBUS-Interface/D02_IN_L: U9.23 (GPA2), U13.6 (O2)
/UNIBUS-Interface/D02_OUT: U15.23 (GPA2), U20.3 (I3)
/UNIBUS-Interface/D03_IN_L: U9.24 (GPA3), U13.9 (O3)
/UNIBUS-Interface/D03_OUT: U15.24 (GPA3), U20.4 (I4)
/UNIBUS-Interface/D04_IN_L: U9.25 (GPA4), U13.12 (O4)
/UNIBUS-Interface/D04_OUT: U15.25 (GPA4), U20.5 (I5)
/UNIBUS-Interface/D05_IN_L: U9.26 (GPA5), U13.15 (O5)
/UNIBUS-Interface/D05_OUT: U15.26 (GPA5), U20.6 (I6)
/UNIBUS-Interface/D06_IN_L: U9.1 (GPB0), U13.16 (O6)
/UNIBUS-Interface/D06_OUT: U15.27 (GPA6), U20.7 (I7)
/UNIBUS-Interface/D07_IN_L: U9.2 (GPB1), U13.19 (O7)
/UNIBUS-Interface/D07_OUT: U15.28 (GPA7), U20.8 (I8)
/UNIBUS-Interface/D08_IN_L: U9.3 (GPB2), U14.2 (O0)
/UNIBUS-Interface/D08_OUT: U15.1 (GPB0), U21.1 (I1)
/UNIBUS-Interface/D09_IN_L: U9.4 (GPB3), U14.5 (O1)
/UNIBUS-Interface/D09_OUT: U15.2 (GPB1), U21.2 (I2)
/UNIBUS-Interface/D10_IN_L: U9.5 (GPB4), U14.6 (O2)
/UNIBUS-Interface/D10_OUT: U15.3 (GPB2), U21.3 (I3)
/UNIBUS-Interface/D11_IN_L: U9.6 (GPB5), U14.9 (O3)
/UNIBUS-Interface/D11_OUT: U15.4 (GPB3), U21.4 (I4)
/UNIBUS-Interface/D12_IN_L: U12.21 (GPA0), U14.12 (O4)
/UNIBUS-Interface/D12_OUT: U15.5 (GPB4), U21.5 (I5)
/UNIBUS-Interface/D13_IN_L: U12.22 (GPA1), U14.15 (O5)
/UNIBUS-Interface/D13_OUT: U15.6 (GPB5), U21.6 (I6)
/UNIBUS-Interface/D14_IN_L: U12.23 (GPA2), U14.16 (O6)
/UNIBUS-Interface/D14_OUT: U15.7 (GPB6), U21.7 (I7)
/UNIBUS-Interface/D15_IN_L: U12.24 (GPA3), U14.19 (O7)
/UNIBUS-Interface/D15_OUT: U15.8 (GPB7), U21.8 (I8)
/UNIBUS-Interface/DCLO_OUT: U8.8 (GPB7), U19.6 (I6)
/UNIBUS-Interface/INIT_OUT: U9.28 (GPA7), U19.7 (I7)
/UNIBUS-Interface/LATCH_DATA: U7.4, U9.8 (GPB7)
/UNIBUS-Interface/MSYN_OUT: U12.28 (GPA7), U19.3 (I3)
/UNIBUS-Interface/SSYN_OUT: U12.8 (GPB7), U19.4 (I4)
BBSY_OUT: U12.5 (GPB4); also elsewhere on the board
C1_OUT: U12.6 (GPB5); also elsewhere on the board
GND: C22.2, C23.2, C24.2, C25.2, C26.2, C27.2, C28.2, C29.2, C30.2, C31.2, U7.7 (GND), U8.10 (VSS), U8.15 (A0), U8.16 (A1), U9.10 (VSS), U9.15 (A0), U10.10 (VSS), U10.15 (A0), U10.16 (A1), U11.10 (VSS), U11.16 (A1), U12.10 (VSS), U13.1 (OE), U13.10 (GND), U14.1 (OE), U14.10 (GND), U15.10 (VSS), U15.15 (A0), U16.10 (VSS), U16.16 (A1), U17.9 (GND), U18.9 (GND), U19.9 (GND), U20.9 (GND), U21.9 (GND); also elsewhere on the board
MCPGROUP0_L: U8.17 (A2), U9.17 (A2), U11.17 (A2), U12.17 (A2); also elsewhere on the board
MCPGROUP1_L: U10.17 (A2), U15.17 (A2), U16.17 (A2); also elsewhere on the board
MSYN_H: U7.3, U8.7 (GPB6), U8.27 (GPA6), U11.7 (GPB6), U11.27 (GPA6)
SACK_OUT: U12.7 (GPB6); also elsewhere on the board
SSYN_H: U7.6, U9.7 (GPB6), U9.27 (GPA6), U12.27 (GPA6), U13.11 (Cp), U14.11 (Cp)
UB_5V: C22.1, C23.1, C24.1, C25.1, C26.1, C27.1, C28.1, C29.1, C30.1, C31.1, U7.1, U7.14 (VCC), U8.9 (VDD), U9.9 (VDD), U9.16 (A1), U10.9 (VDD), U11.9 (VDD), U11.15 (A0), U12.9 (VDD), U12.15 (A0), U12.16 (A1), U13.20 (VCC), U14.20 (VCC), U15.9 (VDD), U15.16 (A1), U16.9 (VDD), U16.15 (A0); also elsewhere on the board
UB_A00_L: U8.21 (GPA0), U17.18 (O1); also elsewhere on the board
UB_A01_L: U8.22 (GPA1), U17.17 (O2); also elsewhere on the board
UB_A02_L: U8.23 (GPA2), U17.16 (O3); also elsewhere on the board
UB_A03_L: U8.24 (GPA3), U17.15 (O4); also elsewhere on the board
UB_A04_L: U8.25 (GPA4), U17.14 (O5); also elsewhere on the board
UB_A05_L: U8.26 (GPA5), U17.13 (O6); also elsewhere on the board
UB_A06_L: U8.1 (GPB0), U17.12 (O7); also elsewhere on the board
UB_A07_L: U8.2 (GPB1), U17.11 (O8); also elsewhere on the board
UB_A08_L: U8.3 (GPB2), U18.18 (O1); also elsewhere on the board
UB_A09_L: U8.4 (GPB3), U18.17 (O2); also elsewhere on the board
UB_A10_L: U8.5 (GPB4), U18.16 (O3); also elsewhere on the board
UB_A11_L: U8.6 (GPB5), U18.15 (O4); also elsewhere on the board
UB_A12_L: U11.21 (GPA0), U18.14 (O5); also elsewhere on the board
UB_A13_L: U11.22 (GPA1), U18.13 (O6); also elsewhere on the board
UB_A14_L: U11.23 (GPA2), U18.12 (O7); also elsewhere on the board
UB_A15_L: U11.24 (GPA3), U18.11 (O8); also elsewhere on the board
UB_A16_L: U11.25 (GPA4), U19.18 (O1); also elsewhere on the board
UB_A17_L: U11.26 (GPA5), U19.17 (O2); also elsewhere on the board
UB_ACLO_L: U12.1 (GPB0), U19.14 (O5); also elsewhere on the board
UB_BBSY_L: U11.4 (GPB3); also elsewhere on the board
UB_BG4_H: U10.1 (GPB0); also elsewhere on the board
UB_BG5_H: U10.2 (GPB1); also elsewhere on the board
UB_BG6_H: U10.3 (GPB2); also elsewhere on the board
UB_BG7_H: U10.4 (GPB3); also elsewhere on the board
UB_BR4_L: U10.21 (GPA0); also elsewhere on the board
UB_BR5_L: U10.22 (GPA1); also elsewhere on the board
UB_BR6_L: U10.23 (GPA2); also elsewhere on the board
UB_BR7_L: U10.24 (GPA3); also elsewhere on the board
UB_C0_L: U11.1 (GPB0); also elsewhere on the board
UB_C1_L: U11.2 (GPB1); also elsewhere on the board
UB_D00_L: U13.3 (D0), U20.18 (O1); also elsewhere on the board
UB_D01_L: U13.4 (D1), U20.17 (O2); also elsewhere on the board
UB_D02_L: U13.7 (D2), U20.16 (O3); also elsewhere on the board
UB_D03_L: U13.8 (D3), U20.15 (O4); also elsewhere on the board
UB_D04_L: U13.13 (D4), U20.14 (O5); also elsewhere on the board
UB_D05_L: U13.14 (D5), U20.13 (O6); also elsewhere on the board
UB_D06_L: U13.17 (D6), U20.12 (O7); also elsewhere on the board
UB_D07_L: U13.18 (D7), U20.11 (O8); also elsewhere on the board
UB_D08_L: U14.3 (D0), U21.18 (O1); also elsewhere on the board
UB_D09_L: U14.4 (D1), U21.17 (O2); also elsewhere on the board
UB_D10_L: U14.7 (D2), U21.16 (O3); also elsewhere on the board
UB_D11_L: U14.8 (D3), U21.15 (O4); also elsewhere on the board
UB_D12_L: U14.13 (D4), U21.14 (O5); also elsewhere on the board
UB_D13_L: U14.14 (D5), U21.13 (O6); also elsewhere on the board
UB_D14_L: U14.17 (D6), U21.12 (O7); also elsewhere on the board
UB_D15_L: U14.18 (D7), U21.11 (O8); also elsewhere on the board
UB_DCLO_L: U12.2 (GPB1), U19.13 (O6); also elsewhere on the board
UB_INIT_L: U12.3 (GPB2), U19.12 (O7); also elsewhere on the board
UB_INTR_L: U11.3 (GPB2); also elsewhere on the board
UB_MSYN_L: U7.2, U19.16 (O3); also elsewhere on the board
UB_NPG_H: U10.26 (GPA5); also elsewhere on the board
UB_NPR_L: U10.25 (GPA4); also elsewhere on the board
UB_PA_L: U12.25 (GPA4); also elsewhere on the board
UB_PB_L: U12.26 (GPA5); also elsewhere on the board
UB_SACK_L: U10.27 (GPA6); also elsewhere on the board
UB_SSYN_L: U7.5, U19.15 (O4); also elsewhere on the board

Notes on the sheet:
! GPA7 and GPB7 not usable as Inputs ! ! 2022 MCP23017 has a bug here !
LATCH on MSYN: ADDR<0:17>, C0,C1 LATCH on SSYN: DATA<0:15> NXM: MSYN without SSYN
HALT request/grant only on 11/34 CPU backplane
UNIBUS drivers. ULN2803 have ~1usec switch time, too slow for running UNIBUS, but OK for single stepping.
DATA guaranteed 75ns after SSYN 0->1 MCP23017 latch time 400ns -> stabilze DATA with 74374
DATA_LATCH H: Latch DATA on UNIBUS SSYN_L H->L H,L,H: force latch when SSYN_L H inactive

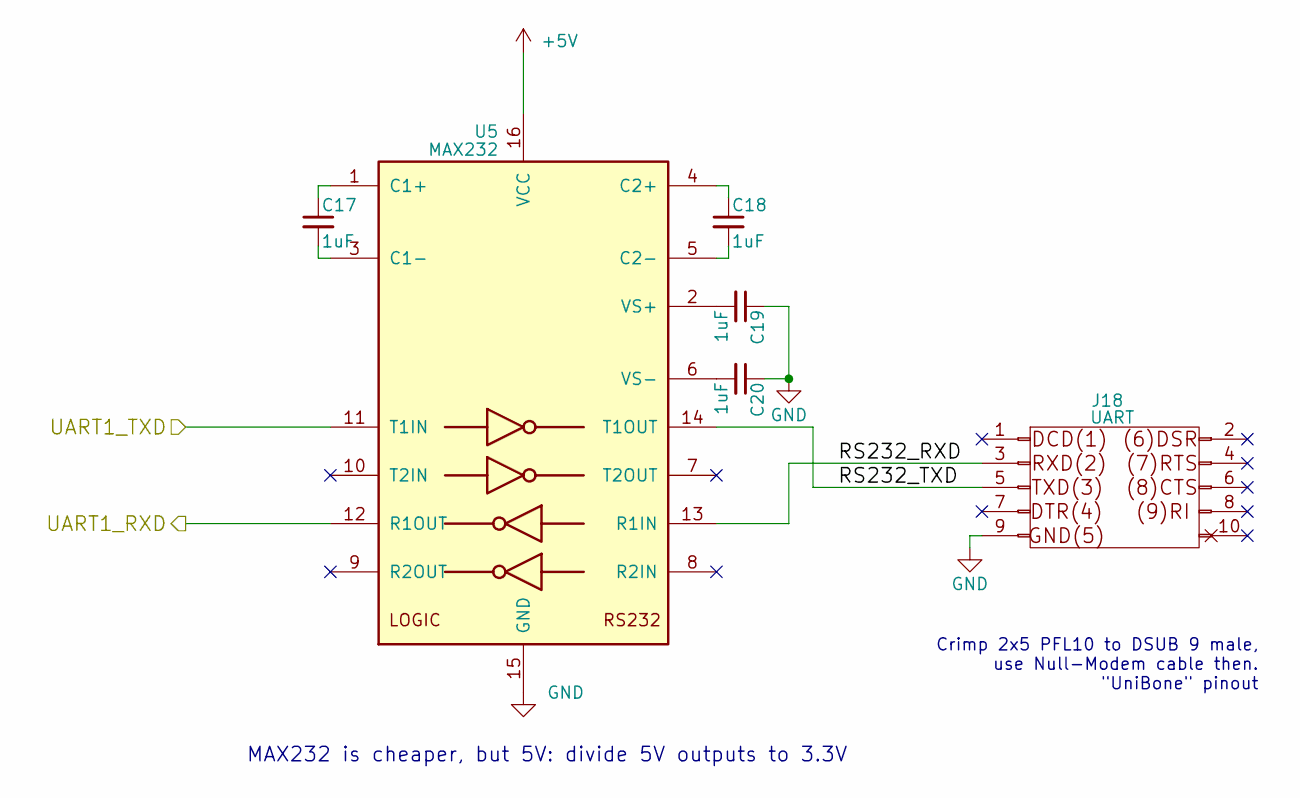
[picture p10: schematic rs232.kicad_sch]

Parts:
C17, C19, C20: 1uF; C_Disc_D4.3mm_W1.9mm_P5.00mm; LCSC C28323
C18: 1uF; C_Disc_D4.3mm_W1.9mm_P5.00mm
J18: UART; IDC-Header_2x05_P2.54mm_Horizontal
U5: MAX232; DIP-16_W7.62mm

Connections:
/RS232_RXD: U5.12 (R1OUT); also elsewhere on the board
/RS232_TXD: U5.11 (T1IN); also elsewhere on the board
/rs232/RS232_RXD: J18.3 (RXD), U5.13 (R1IN)
/rs232/RS232_TXD: J18.5 (TXD), U5.14 (T1OUT)
GND: C19.1, C20.1, J18.9 (GND), U5.15 (GND); also elsewhere on the board
unnamed: C17.1, U5.1 (C1+)
unnamed: C17.2, U5.3 (C1-)
unnamed: C18.1, U5.4 (C2+)
unnamed: C18.2, U5.5 (C2-)
unnamed: C19.2, U5.2 (VS+)
unnamed: C20.2, U5.6 (VS-)
UB_5V: U5.16 (VCC); also elsewhere on the board

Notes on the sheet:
MAX232 is cheaper, but 5V: divide 5V outputs to 3.3V
Crimp 2x5 PFL10 to DSUB 9 male, use Null-Modem cable then. "UniBone" pinout

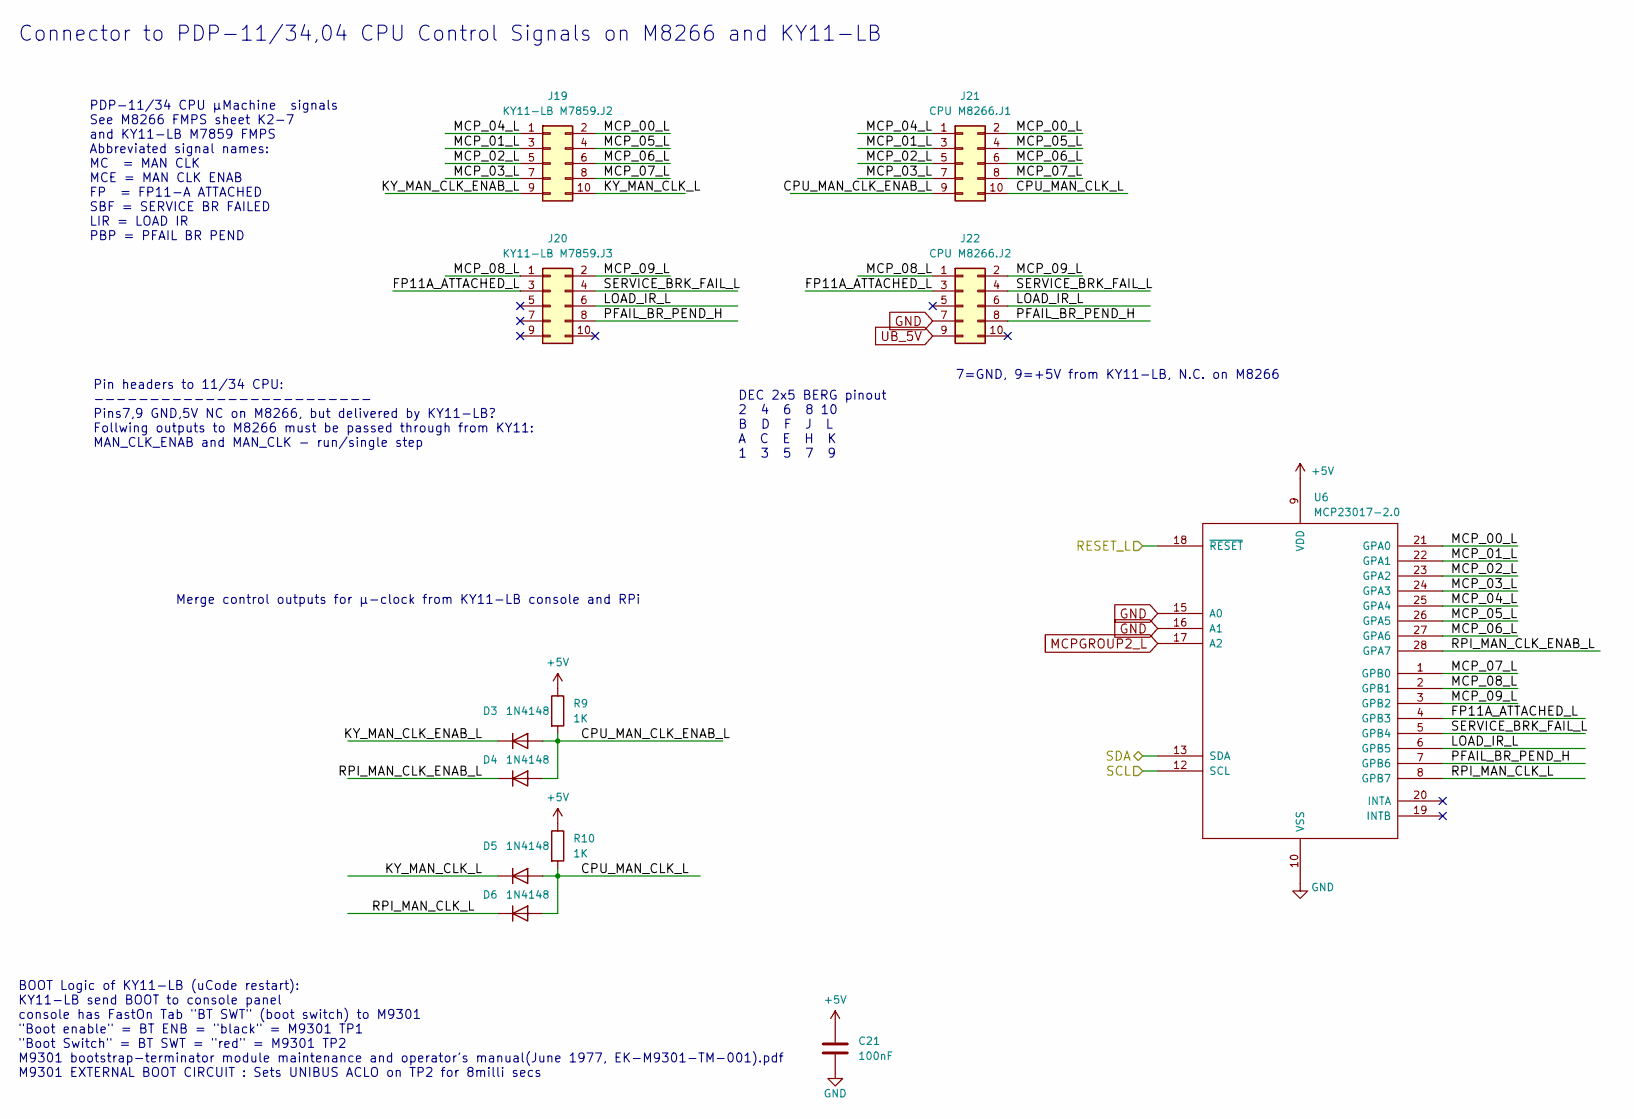
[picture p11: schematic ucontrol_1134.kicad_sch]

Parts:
C21: 100nF; C_Disc_D4.3mm_W1.9mm_P5.00mm
D3, D4, D5, D6: 1N4148; D_DO-35_SOD27_P2.54mm_Vertical_AnodeUp
J19: KY11-LB M7859.J2; IDC-Header_2x05_P2.54mm_Horizontal
J20: KY11-LB M7859.J3; IDC-Header_2x05_P2.54mm_Horizontal
J21: CPU M8266.J1; IDC-Header_2x05_P2.54mm_Horizontal
J22: CPU M8266.J2; IDC-Header_2x05_P2.54mm_Horizontal
R9, R10: 1K; R_Axial_DIN0207_L6.3mm_D2.5mm_P2.54mm_Vertical
U6: MCP23017-2.0; DIP-28_W7.62mm

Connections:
/MCP_RESET_L: U6.18 (~RESET); also elsewhere on the board
/SCL: U6.12 (SCL); also elsewhere on the board
/SDA: U6.13 (SDA); also elsewhere on the board
/ucontrol_1134/CPU_MAN_CLK_ENAB_L: D3.2 (A), D4.2 (A), J21.9, R9.2
/ucontrol_1134/CPU_MAN_CLK_L: D5.2 (A), D6.2 (A), J21.10, R10.2
/ucontrol_1134/FP11A_ATTACHED_L: J20.3, J22.3, U6.4 (GPB3)
/ucontrol_1134/KY_MAN_CLK_ENAB_L: D3.1 (K), J19.9
/ucontrol_1134/KY_MAN_CLK_L: D5.1 (K), J19.10
/ucontrol_1134/LOAD_IR_L: J20.6, J22.6, U6.6 (GPB5)
/ucontrol_1134/MCP_00_L: J19.2, J21.2, U6.21 (GPA0)
/ucontrol_1134/MCP_01_L: J19.3, J21.3, U6.22 (GPA1)
/ucontrol_1134/MCP_02_L: J19.5, J21.5, U6.23 (GPA2)
/ucontrol_1134/MCP_03_L: J19.7, J21.7, U6.24 (GPA3)
/ucontrol_1134/MCP_04_L: J19.1, J21.1, U6.25 (GPA4)
/ucontrol_1134/MCP_05_L: J19.4, J21.4, U6.26 (GPA5)
/ucontrol_1134/MCP_06_L: J19.6, J21.6, U6.27 (GPA6)
/ucontrol_1134/MCP_07_L: J19.8, J21.8, U6.1 (GPB0)
/ucontrol_1134/MCP_08_L: J20.1, J22.1, U6.2 (GPB1)
/ucontrol_1134/MCP_09_L: J20.2, J22.2, U6.3 (GPB2)
/ucontrol_1134/PFAIL_BR_PEND_H: J20.8, J22.8, U6.7 (GPB6)
/ucontrol_1134/RPI_MAN_CLK_ENAB_L: D4.1 (K), U6.28 (GPA7)
/ucontrol_1134/RPI_MAN_CLK_L: D6.1 (K), U6.8 (GPB7)
/ucontrol_1134/SERVICE_BRK_FAIL_L: J20.4, J22.4, U6.5 (GPB4)
GND: C21.2, J22.7, U6.10 (VSS), U6.15 (A0), U6.16 (A1); also elsewhere on the board
MCPGROUP2_L: U6.17 (A2); also elsewhere on the board
UB_5V: C21.1, J22.9, R9.1, R10.1, U6.9 (VDD); also elsewhere on the board

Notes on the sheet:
Merge control outputs for µ-clock from KY11-LB console and RPi
Pin headers to 11/34 CPU: ------------------------- Pins7,9 GND,5V NC on M8266, but delivered by KY11-LB? Follwing outputs to M8266 must be passed through from KY11: MAN_CLK_ENAB and MAN_CLK - run/single step
Connector to PDP-11/34,04 CPU Control Signals on M8266 and KY11-LB
DEC 2x5 BERG pinout 2 4 6 8 10 B D F J L A C E H K 1 3 5 7 9
BOOT Logic of KY11-LB (uCode restart): KY11-LB send BOOT to console panel console has FastOn Tab "BT SWT" (boot switch) to M9301 "Boot enable" = BT ENB = "black" = M9301 TP1 "Boot Switch" = BT SWT = "red" = M9301 TP2 M9301 bootstrap-terminator module maintenance and operator's manual(June 1977, EK-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
PDP-11/34 CPU µMachine signals See M8266 FMPS sheet K2-7 and KY11-LB M7859 FMPS Abbreviated signal names: MC = MAN CLK MCE = MAN CLK ENAB FP = FP11-A ATTACHED SBF = SERVICE BR FAILED LIR = LOAD IR PBP = PFAIL BR PEND
7=GND, 9=+5V from KY11-LB, N.C. on M8266

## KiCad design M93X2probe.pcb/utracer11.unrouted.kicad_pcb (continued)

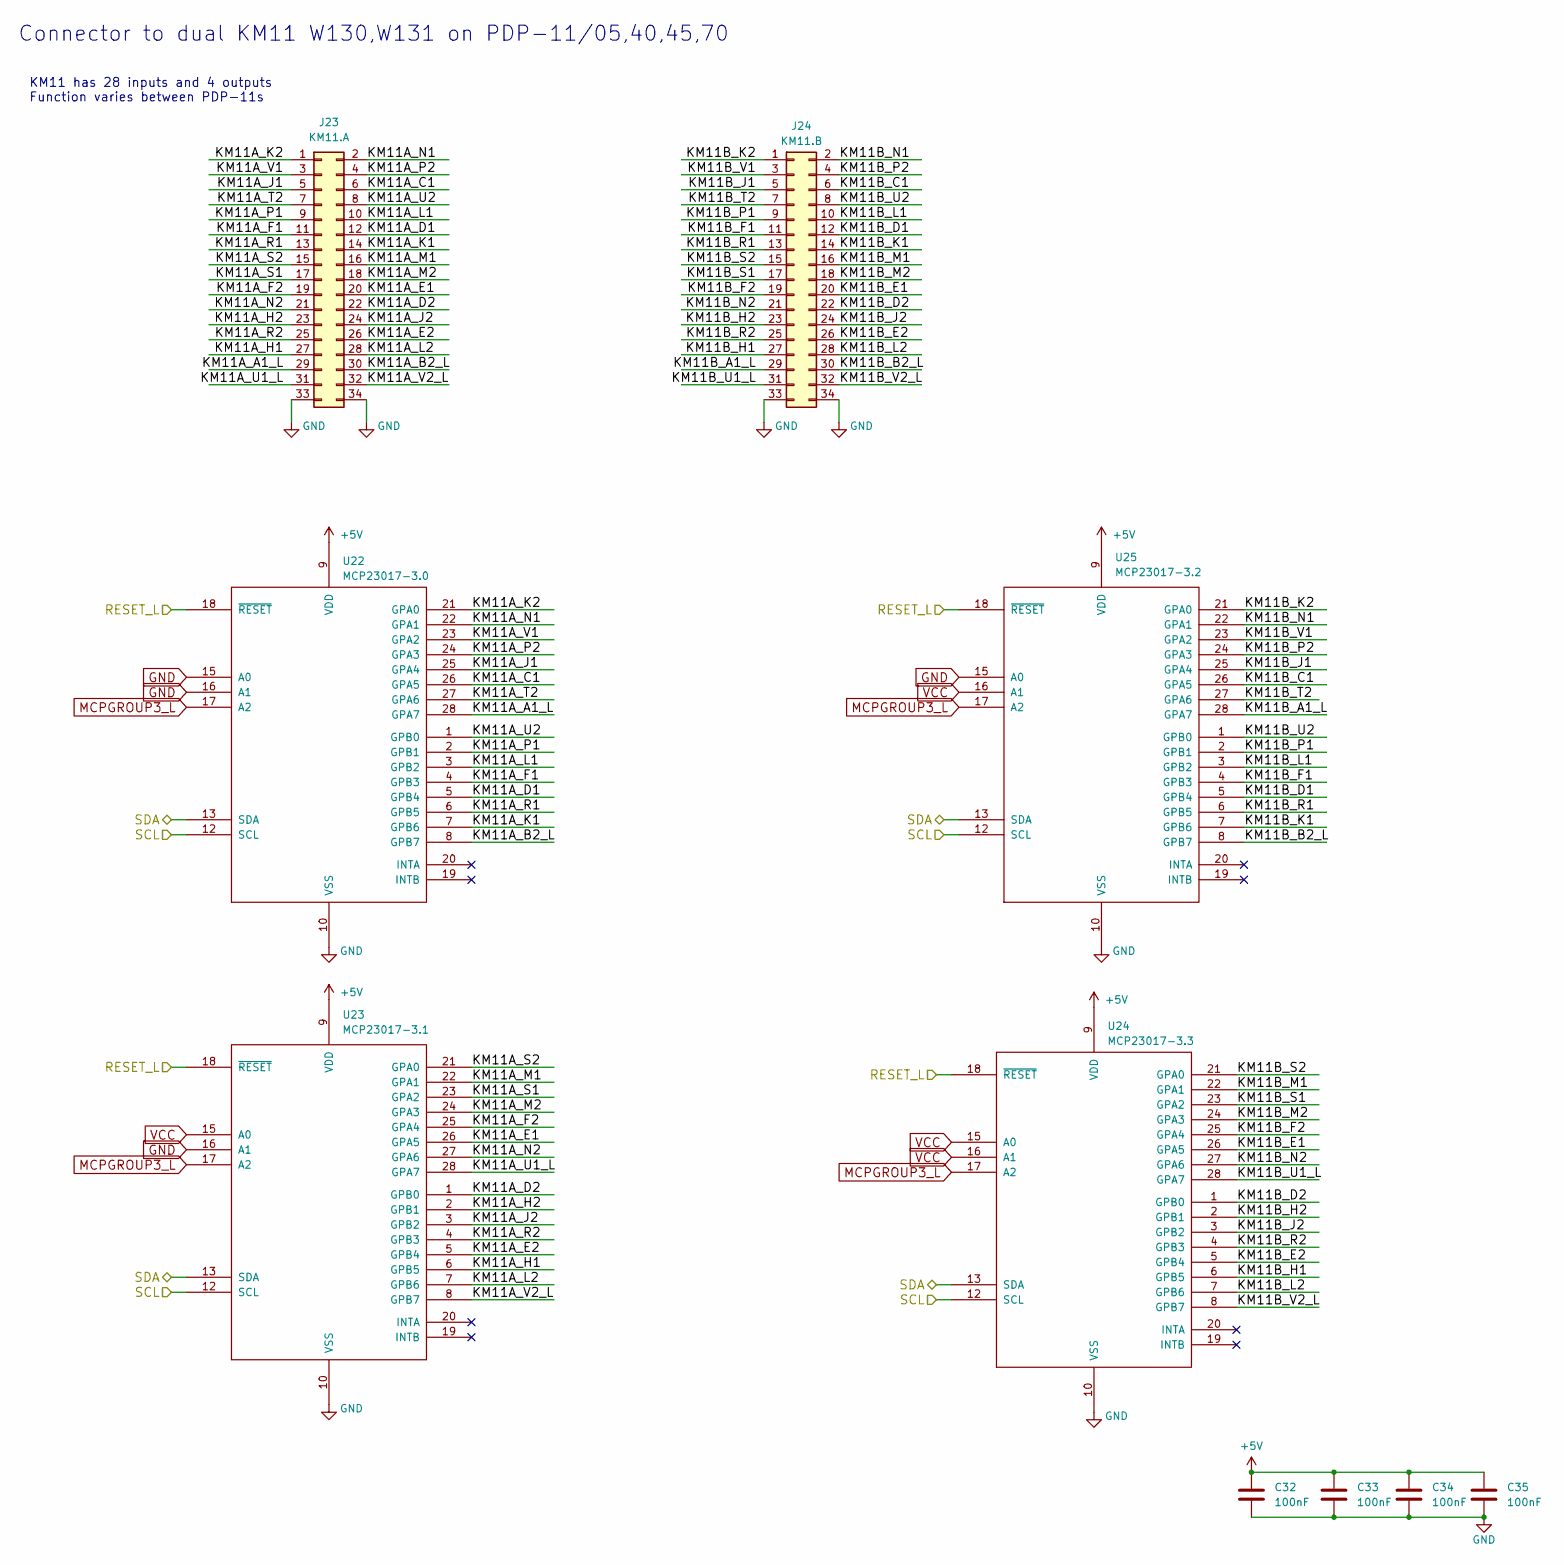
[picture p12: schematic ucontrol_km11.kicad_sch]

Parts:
C32, C33, C34, C35: 100nF; C_Disc_D4.3mm_W1.9mm_P5.00mm
J23: KM11.A; IDC-Header_2x17_P2.54mm_Horizontal
J24: KM11.B; IDC-Header_2x17_P2.54mm_Horizontal
U22: MCP23017-3.0; DIP-28_W7.62mm
U23: MCP23017-3.1; DIP-28_W7.62mm
U24: MCP23017-3.3; DIP-28_W7.62mm
U25: MCP23017-3.2; DIP-28_W7.62mm

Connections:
/MCP_RESET_L: U22.18 (~RESET), U23.18 (~RESET), U24.18 (~RESET), U25.18 (~RESET); also elsewhere on the board
/SCL: U22.12 (SCL), U23.12 (SCL), U24.12 (SCL), U25.12 (SCL); also elsewhere on the board
/SDA: U22.13 (SDA), U23.13 (SDA), U24.13 (SDA), U25.13 (SDA); also elsewhere on the board
/ucontrol_km11/KM11A_A1_L: J23.29, U22.28 (GPA7)
/ucontrol_km11/KM11A_B2_L: J23.30, U22.8 (GPB7)
/ucontrol_km11/KM11A_C1: J23.6, U22.26 (GPA5)
/ucontrol_km11/KM11A_D1: J23.12, U22.5 (GPB4)
/ucontrol_km11/KM11A_D2: J23.22, U23.1 (GPB0)
/ucontrol_km11/KM11A_E1: J23.20, U23.26 (GPA5)
/ucontrol_km11/KM11A_E2: J23.26, U23.5 (GPB4)
/ucontrol_km11/KM11A_F1: J23.11, U22.4 (GPB3)
/ucontrol_km11/KM11A_F2: J23.19, U23.25 (GPA4)
/ucontrol_km11/KM11A_H1: J23.27, U23.6 (GPB5)
/ucontrol_km11/KM11A_H2: J23.23, U23.2 (GPB1)
/ucontrol_km11/KM11A_J1: J23.5, U22.25 (GPA4)
/ucontrol_km11/KM11A_J2: J23.24, U23.3 (GPB2)
/ucontrol_km11/KM11A_K1: J23.14, U22.7 (GPB6)
/ucontrol_km11/KM11A_K2: J23.1, U22.21 (GPA0)
/ucontrol_km11/KM11A_L1: J23.10, U22.3 (GPB2)
/ucontrol_km11/KM11A_L2: J23.28, U23.7 (GPB6)
/ucontrol_km11/KM11A_M1: J23.16, U23.22 (GPA1)
/ucontrol_km11/KM11A_M2: J23.18, U23.24 (GPA3)
/ucontrol_km11/KM11A_N1: J23.2, U22.22 (GPA1)
/ucontrol_km11/KM11A_N2: J23.21, U23.27 (GPA6)
/ucontrol_km11/KM11A_P1: J23.9, U22.2 (GPB1)
/ucontrol_km11/KM11A_P2: J23.4, U22.24 (GPA3)
/ucontrol_km11/KM11A_R1: J23.13, U22.6 (GPB5)
/ucontrol_km11/KM11A_R2: J23.25, U23.4 (GPB3)
/ucontrol_km11/KM11A_S1: J23.17, U23.23 (GPA2)
/ucontrol_km11/KM11A_S2: J23.15, U23.21 (GPA0)
/ucontrol_km11/KM11A_T2: J23.7, U22.27 (GPA6)
/ucontrol_km11/KM11A_U1_L: J23.31, U23.28 (GPA7)
/ucontrol_km11/KM11A_U2: J23.8, U22.1 (GPB0)
/ucontrol_km11/KM11A_V1: J23.3, U22.23 (GPA2)
/ucontrol_km11/KM11A_V2_L: J23.32, U23.8 (GPB7)
/ucontrol_km11/KM11B_A1_L: J24.29, U25.28 (GPA7)
/ucontrol_km11/KM11B_B2_L: J24.30, U25.8 (GPB7)
/ucontrol_km11/KM11B_C1: J24.6, U25.26 (GPA5)
/ucontrol_km11/KM11B_D1: J24.12, U25.5 (GPB4)
/ucontrol_km11/KM11B_D2: J24.22, U24.1 (GPB0)
/ucontrol_km11/KM11B_E1: J24.20, U24.26 (GPA5)
/ucontrol_km11/KM11B_E2: J24.26, U24.5 (GPB4)
/ucontrol_km11/KM11B_F1: J24.11, U25.4 (GPB3)
/ucontrol_km11/KM11B_F2: J24.19, U24.25 (GPA4)
/ucontrol_km11/KM11B_H1: J24.27, U24.6 (GPB5)
/ucontrol_km11/KM11B_H2: J24.23, U24.2 (GPB1)
/ucontrol_km11/KM11B_J1: J24.5, U25.25 (GPA4)
/ucontrol_km11/KM11B_J2: J24.24, U24.3 (GPB2)
/ucontrol_km11/KM11B_K1: J24.14, U25.7 (GPB6)
/ucontrol_km11/KM11B_K2: J24.1, U25.21 (GPA0)
/ucontrol_km11/KM11B_L1: J24.10, U25.3 (GPB2)
/ucontrol_km11/KM11B_L2: J24.28, U24.7 (GPB6)
/ucontrol_km11/KM11B_M1: J24.16, U24.22 (GPA1)
/ucontrol_km11/KM11B_M2: J24.18, U24.24 (GPA3)
/ucontrol_km11/KM11B_N1: J24.2, U25.22 (GPA1)
/ucontrol_km11/KM11B_N2: J24.21, U24.27 (GPA6)
/ucontrol_km11/KM11B_P1: J24.9, U25.2 (GPB1)
/ucontrol_km11/KM11B_P2: J24.4, U25.24 (GPA3)
/ucontrol_km11/KM11B_R1: J24.13, U25.6 (GPB5)
/ucontrol_km11/KM11B_R2: J24.25, U24.4 (GPB3)
/ucontrol_km11/KM11B_S1: J24.17, U24.23 (GPA2)
/ucontrol_km11/KM11B_S2: J24.15, U24.21 (GPA0)
/ucontrol_km11/KM11B_T2: J24.7, U25.27 (GPA6)
/ucontrol_km11/KM11B_U1_L: J24.31, U24.28 (GPA7)
/ucontrol_km11/KM11B_U2: J24.8, U25.1 (GPB0)
/ucontrol_km11/KM11B_V1: J24.3, U25.23 (GPA2)
/ucontrol_km11/KM11B_V2_L: J24.32, U24.8 (GPB7)
GND: C32.2, C33.2, C34.2, C35.2, J23.33, J23.34, J24.33, J24.34, U22.10 (VSS), U22.15 (A0), U22.16 (A1), U23.10 (VSS), U23.16 (A1), U24.10 (VSS), U25.10 (VSS), U25.15 (A0); also elsewhere on the board
MCPGROUP3_L: U22.17 (A2), U23.17 (A2), U24.17 (A2), U25.17 (A2); also elsewhere on the board
UB_5V: C32.1, C33.1, C34.1, C35.1, U22.9 (VDD), U23.9 (VDD), U23.15 (A0), U24.9 (VDD), U24.15 (A0), U24.16 (A1), U25.9 (VDD), U25.16 (A1); also elsewhere on the board

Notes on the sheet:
Connector to dual KM11 W130,W131 on PDP-11/05,40,45,70
KM11 has 28 inputs and 4 outputs Function varies between PDP-11s

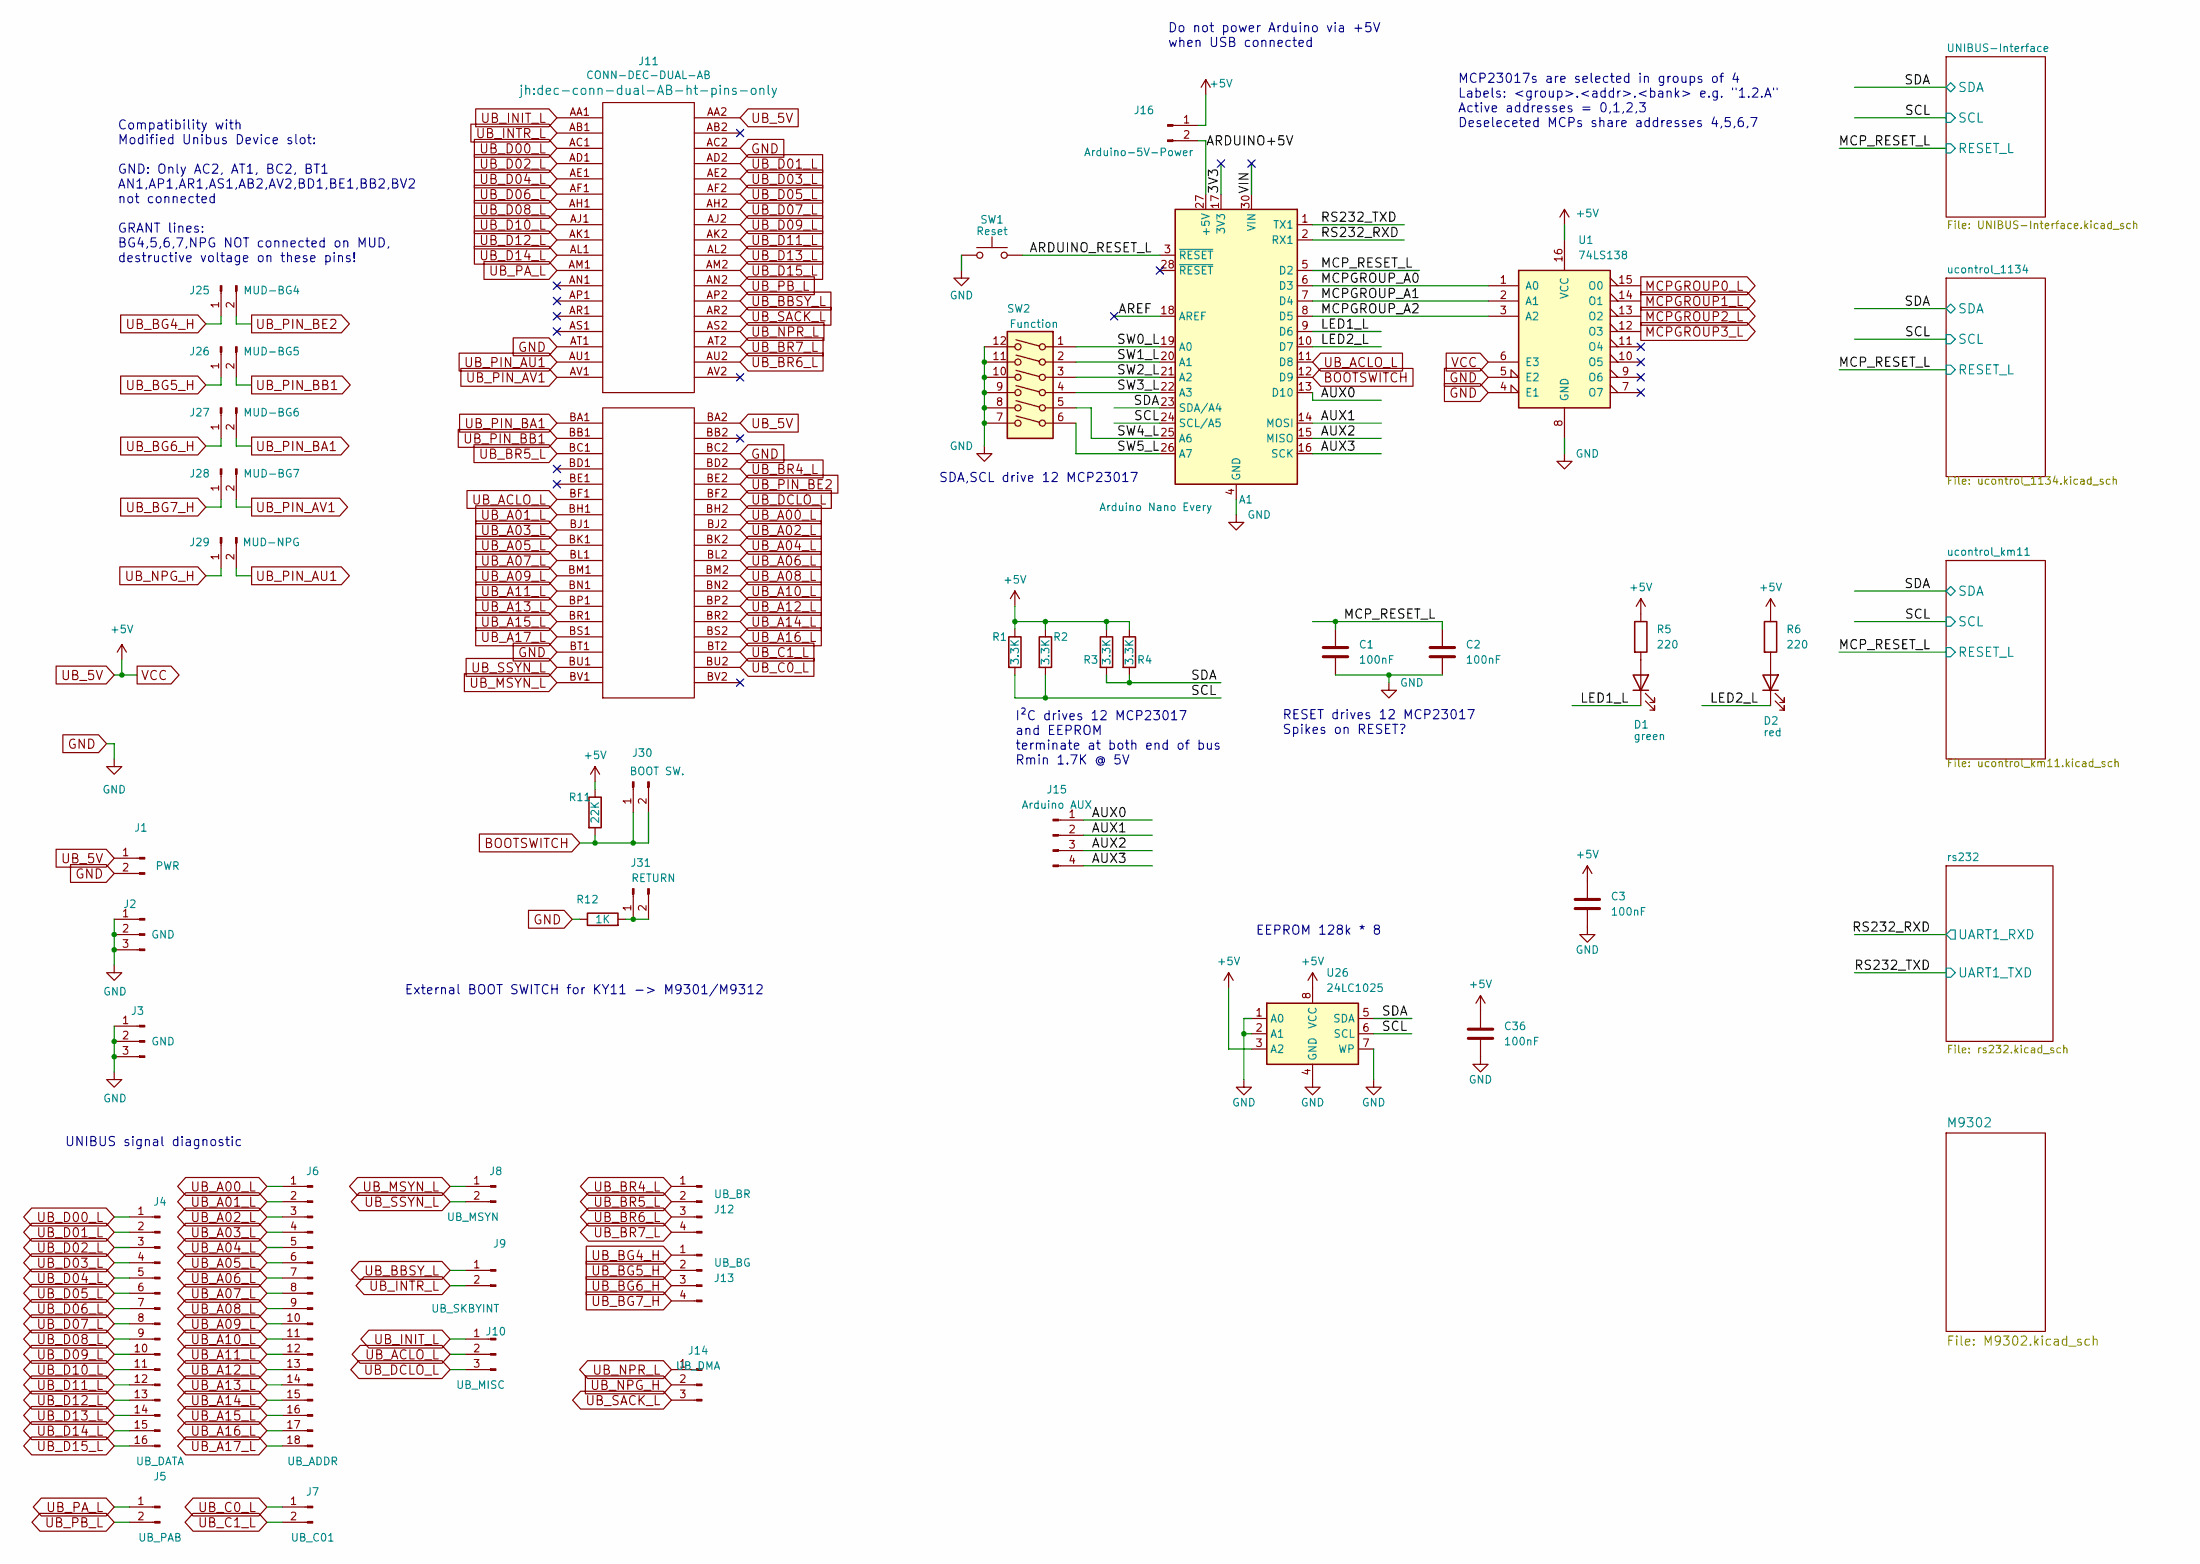
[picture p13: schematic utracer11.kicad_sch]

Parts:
A1: Arduino Nano Every; Arduino_Nano
C1, C2, C3, C36: 100nF; C_Disc_D4.3mm_W1.9mm_P5.00mm
D1: green; LED_D3.0mm_Horizontal_O3.81mm_Z2.0mm
D2: red; LED_D3.0mm_Horizontal_O3.81mm_Z2.0mm
J1: PWR; PinHeader_1x02_P2.54mm_Vertical
J2, J3: GND; PinHeader_1x03_P2.54mm_Vertical
J4: UB_DATA; PinHeader_1x16_P2.54mm_Vertical
J5: UB_PAB; PinHeader_1x02_P2.54mm_Vertical
J6: UB_ADDR; PinHeader_1x18_P2.54mm_Vertical
J7: UB_C01; PinHeader_1x02_P2.54mm_Vertical
J8: UB_MSYN; PinHeader_1x02_P2.54mm_Vertical
J9: UB_SKBYINT; PinHeader_1x02_P2.54mm_Vertical
J10: UB_MISC; PinHeader_1x03_P2.54mm_Vertical
J11: CONN-DEC-DUAL-AB; dec-conn-dual-AB-ht-pins-only
J12: UB_BR; PinHeader_1x04_P2.54mm_Vertical
J13: UB_BG; PinHeader_1x04_P2.54mm_Vertical
J14: UB_DMA; PinHeader_1x03_P2.54mm_Vertical
J15: Arduino AUX; PinHeader_1x04_P2.54mm_Vertical
J16: Arduino-5V-Power; PinHeader_1x02_P2.54mm_Vertical
J25: MUD-BG4; PinHeader_1x02_P2.54mm_Vertical
J26: MUD-BG5; PinHeader_1x02_P2.54mm_Vertical
J27: MUD-BG6; PinHeader_1x02_P2.54mm_Vertical
J28: MUD-BG7; PinHeader_1x02_P2.54mm_Vertical
J29: MUD-NPG; PinHeader_1x02_P2.54mm_Vertical
J30: BOOT SW.; SolderWirePad_1x02_P5.08mm_Drill1.5mm
J31: RETURN; SolderWirePad_1x02_P5.08mm_Drill1.5mm
R1, R2, R3, R4: 3.3K; R_Axial_DIN0207_L6.3mm_D2.5mm_P2.54mm_Vertical; LCSC C26010
R5, R6: 220; R_Axial_DIN0207_L6.3mm_D2.5mm_P2.54mm_Vertical
R11: 22K; R_Axial_DIN0207_L6.3mm_D2.5mm_P7.62mm_Horizontal; LCSC C26010
R12: 1K; R_Axial_DIN0207_L6.3mm_D2.5mm_P7.62mm_Horizontal; LCSC C26010
SW1: Reset; SW_Tactile_SPST_Angled_PTS645Vx58-2LFS
SW2: Function; SW_DIP_SPSTx06_Piano_CTS_Series194-6MSTN_W7.62mm_P2.54mm
U1: 74LS138; DIP-16_W7.62mm
U26: 24LC1025; DIP-8_W7.62mm

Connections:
/3V3: A1.17 (3V3)
/ARDUINO+5V: A1.27 (+5V), J16.2
/ARDUINO_RESET_L: A1.3 (~RESET), SW1.2
/AREF: A1.18 (AREF)
/AUX0: A1.13 (D10), J15.1
/AUX1: A1.14 (MOSI), J15.2
/AUX2: A1.15 (MISO), J15.3
/AUX3: A1.16 (SCK), J15.4
/LED1_L: A1.9 (D6), D1.1 (K)
/LED2_L: A1.10 (D7), D2.1 (K)
/MCPGROUP_A0: A1.6 (D3), U1.1 (A0)
/MCPGROUP_A1: A1.7 (D4), U1.2 (A1)
/MCPGROUP_A2: A1.8 (D5), U1.3 (A2)
/MCP_RESET_L: A1.5 (D2), C1.1, C2.1; also elsewhere on the board
/RS232_RXD: A1.2 (RX1); also elsewhere on the board
/RS232_TXD: A1.1 (TX1); also elsewhere on the board
/SCL: A1.24 (SCL/A5), R1.2, R2.2, U26.6 (SCL); also elsewhere on the board
/SDA: A1.23 (SDA/A4), R3.2, R4.2, U26.5 (SDA); also elsewhere on the board
/SW0_L: A1.19 (A0), SW2.1
/SW1_L: A1.20 (A1), SW2.2
/SW2_L: A1.21 (A2), SW2.3
/SW3_L: A1.22 (A3), SW2.4
/SW4_L: A1.25 (A6), SW2.5
/SW5_L: A1.26 (A7), SW2.6
/VIN: A1.30 (VIN)
BOOTSWITCH: A1.12 (D9), J30.1, J30.2, R11.2
GND: A1.4 (GND), A1.29 (GND), C1.2, C2.2, C3.2, C36.2, J1.2, J2.1, J2.2, J2.3, J3.1, J3.2, J3.3, J11.AC2, J11.AT1, J11.BC2, J11.BT1, R12.1, SW1.1, SW2.7, SW2.8, SW2.9, SW2.10, SW2.11, SW2.12, U1.4 (E1), U1.5 (E2), U1.8 (GND), U26.1 (A0), U26.2 (A1), U26.4 (GND), U26.7 (WP); also elsewhere on the board
MCPGROUP0_L: U1.15 (O0); also elsewhere on the board
MCPGROUP1_L: U1.14 (O1); also elsewhere on the board
MCPGROUP2_L: U1.13 (O2); also elsewhere on the board
MCPGROUP3_L: U1.12 (O3); also elsewhere on the board
unnamed: D1.2 (A), R5.2
unnamed: D2.2 (A), R6.2
unnamed: J31.1, J31.2, R12.2
UB_5V: C3.1, C36.1, J1.1, J11.AA2, J11.BA2, J16.1, R1.1, R2.1, R3.1, R4.1, R5.1, R6.1, R11.1, U1.6 (E3), U1.16 (VCC), U26.3 (A2), U26.8 (VCC); also elsewhere on the board
UB_A00_L: J6.1, J11.BH2; also elsewhere on the board
UB_A01_L: J6.2, J11.BH1; also elsewhere on the board
UB_A02_L: J6.3, J11.BJ2; also elsewhere on the board
UB_A03_L: J6.4, J11.BJ1; also elsewhere on the board
UB_A04_L: J6.5, J11.BK2; also elsewhere on the board
UB_A05_L: J6.6, J11.BK1; also elsewhere on the board
UB_A06_L: J6.7, J11.BL2; also elsewhere on the board
UB_A07_L: J6.8, J11.BL1; also elsewhere on the board
UB_A08_L: J6.9, J11.BM2; also elsewhere on the board
UB_A09_L: J6.10, J11.BM1; also elsewhere on the board
UB_A10_L: J6.11, J11.BN2; also elsewhere on the board
UB_A11_L: J6.12, J11.BN1; also elsewhere on the board
UB_A12_L: J6.13, J11.BP2; also elsewhere on the board
UB_A13_L: J6.14, J11.BP1; also elsewhere on the board
UB_A14_L: J6.15, J11.BR2; also elsewhere on the board
UB_A15_L: J6.16, J11.BR1; also elsewhere on the board
UB_A16_L: J6.17, J11.BS2; also elsewhere on the board
UB_A17_L: J6.18, J11.BS1; also elsewhere on the board
UB_ACLO_L: A1.11 (D8), J10.2, J11.BF1; also elsewhere on the board
UB_BBSY_L: J9.1, J11.AP2; also elsewhere on the board
UB_BG4_H: J13.1, J25.1; also elsewhere on the board
UB_BG5_H: J13.2, J26.1; also elsewhere on the board
UB_BG6_H: J13.3, J27.1; also elsewhere on the board
UB_BG7_H: J13.4, J28.1; also elsewhere on the board
UB_BR4_L: J11.BD2, J12.1; also elsewhere on the board
UB_BR5_L: J11.BC1, J12.2; also elsewhere on the board
UB_BR6_L: J11.AU2, J12.3; also elsewhere on the board
UB_BR7_L: J11.AT2, J12.4; also elsewhere on the board
UB_C0_L: J7.1, J11.BU2; also elsewhere on the board
UB_C1_L: J7.2, J11.BT2; also elsewhere on the board
UB_D00_L: J4.1, J11.AC1; also elsewhere on the board
UB_D01_L: J4.2, J11.AD2; also elsewhere on the board
UB_D02_L: J4.3, J11.AD1; also elsewhere on the board
UB_D03_L: J4.4, J11.AE2; also elsewhere on the board
UB_D04_L: J4.5, J11.AE1; also elsewhere on the board
UB_D05_L: J4.6, J11.AF2; also elsewhere on the board
UB_D06_L: J4.7, J11.AF1; also elsewhere on the board
UB_D07_L: J4.8, J11.AH2; also elsewhere on the board
UB_D08_L: J4.9, J11.AH1; also elsewhere on the board
UB_D09_L: J4.10, J11.AJ2; also elsewhere on the board
UB_D10_L: J4.11, J11.AJ1; also elsewhere on the board
UB_D11_L: J4.12, J11.AK2; also elsewhere on the board
UB_D12_L: J4.13, J11.AK1; also elsewhere on the board
UB_D13_L: J4.14, J11.AL2; also elsewhere on the board
UB_D14_L: J4.15, J11.AL1; also elsewhere on the board
UB_D15_L: J4.16, J11.AM2; also elsewhere on the board
UB_DCLO_L: J10.3, J11.BF2; also elsewhere on the board
UB_INIT_L: J10.1, J11.AA1; also elsewhere on the board
UB_INTR_L: J9.2, J11.AB1; also elsewhere on the board
UB_MSYN_L: J8.1, J11.BV1; also elsewhere on the board
UB_NPG_H: J14.2, J29.1; also elsewhere on the board
UB_NPR_L: J11.AS2, J14.1; also elsewhere on the board
UB_PA_L: J5.1, J11.AM1; also elsewhere on the board
UB_PB_L: J5.2, J11.AN2; also elsewhere on the board
UB_PIN_AU1: J11.AU1, J29.2
UB_PIN_AV1: J11.AV1, J28.2
UB_PIN_BA1: J11.BA1, J27.2
UB_PIN_BB1: J11.BB1, J26.2
UB_PIN_BE2: J11.BE2, J25.2
UB_SACK_L: J11.AR2, J14.3; also elsewhere on the board
UB_SSYN_L: J8.2, J11.BU1; also elsewhere on the board

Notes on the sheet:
Do not power Arduino via +5V when USB connected
Compatibility with Modified Unibus Device slot: GND: Only AC2, AT1, BC2, BT1 AN1,AP1,AR1,AS1,AB2,AV2,BD1,BE1,BB2,BV2 not connected GRANT lines: BG4,5,6,7,NPG NOT connected on MUD, destructive voltage on these pins!
External BOOT SWITCH for KY11 -> M9301/M9312
MCP23017s are selected in groups of 4 Labels: <group>.<addr>.<bank> e.g. "1.2.A" Active addresses = 0,1,2,3 Deseleceted MCPs share addresses 4,5,6,7
UNIBUS signal diagnostic
I²C drives 12 MCP23017 and EEPROM terminate at both end of bus Rmin 1.7K @ 5V
RESET drives 12 MCP23017 Spikes on RESET?
EEPROM 128k * 8
SDA,SCL drive 12 MCP23017

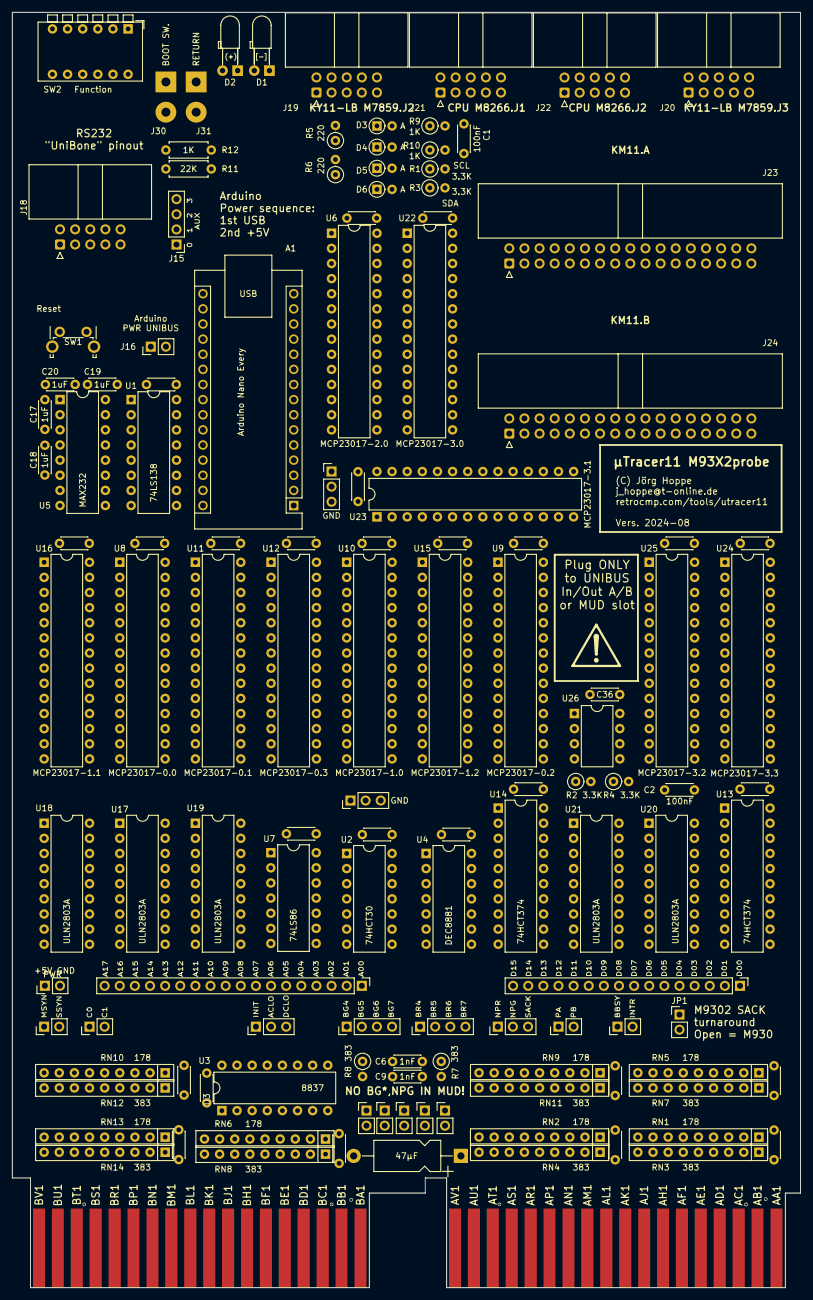
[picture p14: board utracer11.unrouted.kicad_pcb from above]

Board: 4 copper layers, 132.3 x 214.1 mm, 128 parts (0 on the bottom side), 253 nets.

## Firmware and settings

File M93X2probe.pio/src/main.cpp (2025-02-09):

/* main.cpp - Setup and main loop

  uTracer11 Probe is a board plugged into the UNIBUS terminator slot
  - senses UNIBUS signals
  - senses complete DATI/DATO cycles
  - executed EXAM and DEPOSIT on UNIBUS
  - senses uProgram Counter and diagnostics signals
     on the M8266 header for PDP-11/34 CPU
  - generates µClock on the M8266 header
  - senses uProgram Counter / 2x28 diagnostics signals
    on two KM11 diagnostic boards KM11A/KM11B
  - generates 2x4 signals on KM11
    Use of KM11 depends on PDP-11 model under test

  Serial protocol see "controller.cpp"
*/
#include <Arduino.h>
#include <avr/wdt.h>

#include "bootlogic.h"
#include "console.h"
#include "controller.h"
#include "hardware.h"
#include "ky11lb.h"
#include "messages.h"
#include "unibus.h"

void setup() {
    // put your setup code here, to run once:
    // NO Watchdog ... we have long running loops
    wdt_disable();

    theLogger.setup();
    theHardware.setup();
    theKY11LB.setup();
    theUnibus.setup();

    LOG("\n\M93X2probe compiled %s %s\n", __DATE__, __TIME__);

    theConsole.setup(&Serial1, 115200);
    //theConsole.printStrF("\nHello world!\n");
    //while(1) ;

    theBootLogic.setup();

    // output response to "VERSION" command, is also answer to RESET
    theConsole.printStrF("\n%s\n", theController.versionAsResponse(MsgTag::none).render());

	/*
    // test print out, via controller callback
    thePdp11Data.setIterationCallback(&theController, &Pdp11DataUser::onPdp11DataIteration);
    auto recList = thePdp11Data.getRecordListByNumber(1);
    thePdp11Data.iterate(recList, 1);
    */
}

void loop() {
    uint32_t cur_millis = millis();

    // put your main code here, to run repeatedly:
    theHardware.loop(cur_millis);
    theConsole.loopRcv();
    theConsole.loopXmt();

    theBootLogic.loop(cur_millis);
    // BOOT on ACLO or boot switch

    theController.loop();

    if (theConsole.stringReceived) {
        // one line received, buffer valid until next .service()
        char *line = theConsole.getAndClearRcvString();
        char *response = theController.doHostCommand(line);
        if (response != nullptr)
            theConsole.xmtLine(response); // start output
    }
    /*
        // something to sent? Wait until buffer clear
          if (strlen(event_buffer) && theConsole.stringTransmitted) {
            theConsole.xmtLine("!"+event_message) ; // start output
            */
}

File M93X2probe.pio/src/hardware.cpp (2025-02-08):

/* hardware.cpp - low level functions for onboard IO, LEDs and switches
    Bits: pos of bits in RS232 data
    KY11LB interface:
    MCP     Ports   Bits    Signal
    2.0     A0..A6  in0..6  MCP0..6
            B0..B2  in7..9  MCP7..9
            B3      in10
            B4
            B5
            B6
            B7
            A7      out MAN CLK ENABLE

 */
#include <Arduino.h>
#include <Wire.h>

#include "console.h" // debug logging

#include "hardware.h" // own stuff
#include "mcp23017.h"

Hardware theHardware;

// declare reset function at address 0
void (*resetFunc)(void) = 0;


void LED::setup(int _gpio) {
    gpio = _gpio;
    pinMode(gpio, OUTPUT);
    next_on_millis = 0;
    next_off_millis = 0;
    digitalWrite(gpio, 1); // output inverting: OFF
    on = false;
}

// let LED blink.
// feed in global time millis() by caller
void LED::loop(uint32_t cur_millis) {
    if (on) {
        // conditions to switch OFF: timeout or permament ON?
        if (cur_millis >= next_off_millis && off_period_millis > 0) {
            // change state, setup next state change time
            next_off_millis = cur_millis + on_period_millis;
            next_on_millis = cur_millis + off_period_millis;
            digitalWrite(gpio, 1); // output inverting: OFF
            on = false;
        }
    } else {
        // conditions to switch ON: or permament off?
        if (cur_millis >= next_on_millis && on_period_millis > 0) {
            // change state, setup next state change time
            next_off_millis = cur_millis + on_period_millis;
            next_on_millis = cur_millis + off_period_millis;
            digitalWrite(gpio, 0); // output inverting: ON
            on = true;
        }
    }
}

// just digital outputs

void PinAux::setupInput(int _gpio) {
    gpio = _gpio;
    pinMode(gpio, INPUT_PULLUP);
}

void PinAux::setupOutput(int _gpio) {
    gpio = _gpio;
    pinMode(gpio, OUTPUT);
    digitalWrite(gpio, 0); // OFF
}

void PinAux::setVal(bool val) {
    digitalWrite(gpio, val);
}

// 6 fold switch connected to A0..3,A6,A7
void OptionSwitch::setup() {
    pinMode(A0, INPUT_PULLUP); // inverting, switches to GND
    pinMode(A1, INPUT_PULLUP);
    pinMode(A2, INPUT_PULLUP);
    pinMode(A3, INPUT_PULLUP);
    pinMode(A6, INPUT_PULLUP);
    pinMode(A7, INPUT_PULLUP);
}

uint8_t OptionSwitch::getVal() {
    uint8_t result = 0;
    // inputs inverting
    if (!digitalRead(A0))
        result |= 0x01;
    if (!digitalRead(A1))
        result |= 0x02;
    if (!digitalRead(A2))
        result |= 0x04;
    if (!digitalRead(A3))
        result |= 0x08;
    if (!digitalRead(A6))
        result |= 0x10;
    if (!digitalRead(A7))
        result |= 0x20;
    return result;
}

// program MCP23017s registers for 11/34 KY11LB interface
// default levels for KY11LB header outputs depend on PDP-11 model
void Hardware::setupMcpKY11LBRegisters() {

    // First define outpt pin levels, the switch pins to OUTPUT
    // KY11LB
    // Levels depend on the PDP-11 we're plugged in!
    theHardware.mcpWriteOptimization = false;      // force setup
    mcp[2][0].write(Mcp23017::Register::OLATA, 0); // init all 0
    mcp[2][0].write(Mcp23017::Register::OLATB, 0);
    mcp[2][0].write(Mcp23017::Register::GPPUA, 0xff); // inputs 100kOhm pullup
    mcp[2][0].write(Mcp23017::Register::GPPUB, 0xff); // for test with unconnected KY11

    // CLOCK outputs H=inactive (see diode logic), 
    // so KY11LB can control by default
    mcp[2][0].writeBit(Mcp23017::Register::OLATA, 7, 1); // man_clk_enab_l = inactive
    mcp[2][0].writeBit(Mcp23017::Register::OLATB, 7, 1); // man_clk_l = inactive, for active pulse

    // enable outputs
    //  bit "1" = in "0" = out
    mcp[2][0].write(Mcp23017::Register::IODIRA, 0x7f); // GPA7 output
    mcp[2][0].write(Mcp23017::Register::IODIRB, 0x7f); // GPB7 output
    theHardware.mcpWriteOptimization = true;
}
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

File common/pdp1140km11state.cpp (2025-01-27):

/* Encode/decode KM11 signals for the PDP-11/40

Remember: its a long way to transmit a  CPU simulator variable 
 over the message interface to the GUI.
1. CPU simulator var "mpc"			CPU
2. logical KM11A signals  ("PUPP")	Km11 overlay
3. KM11 flip chip signals (K2,N1,V1,P1,....)
4. compact "gpio" hex values
 

Signal layout on DEC KM11A (CPU)
    KD11-A Maintenance Console Overlay (A-SS-5509081-0-12)

pupp6   pupp3   pupp0   bupp6   bupp3   bupp0   c
                                                        ----    mstop
pupp7   pupp4   pupp1   bupp7   bupp4   bupp1   v
                                                        mclk    mclk_enab
pupp8   pupp5   pupp2   bupp8   bupp5   bupp2   z

 --      --     trap    ssyn    msyn    t       n


Signal layout on DEC KM11B (MMU / FPU)
    KT11-D, KE11-E,F Maintenance Console Overlay (A-SS-5509081-0-13)

pba15   pba12   pba09   pba06   b15     dr00    epsc
                                                        ----    ----
pba16   pba13   pba10   pba07   ecn00   dr09    epsv
                                                        ----    ----
pba17   pba14   pba11   pba08   expunfl msr00   epsz

roma    romb    romc    romd    expovfl msr01   epsn

FlipChip signals on slot F1:
K2      J1      P1      R1      S1      N2      R2
N1      C1      L1      K1      M2      D2      E2       A1     B2
V1      T2      F1      S2      F2      H2      H1       U1     V2
P2      U2      D1      M1      E1      J2      L2


Signals indices [col,row] on M93X2probe KM11 PCB: see messages.txt

*/

#include "utils.h"
#include "pdp1140km11state.h"


// GUI evaluates raw KM11 signals from PDP11/40 or simulator
void Pdp1140KM11AState::inputsFromKM11AResponse(ResponseKM11Signals* respKm11A)
{
    if (respKm11A->channel != 'A')
        LOGERROR("Pdp1140KM11Signals::inputsFromKM11A: channel A expected, is %c", respKm11A->channel);
    // for bit-encoding see PCB of M93X2probe
    // get FlipChip Signal bits from GPIO, same for all KM11s
    respKm11A->getFlipchipSignalsFromGpioVals();

    // compose state vars fom bits, different for all KM11s
    pupp = SETBIT(respKm11A->K2, 6) | SETBIT(respKm11A->N1, 7) | SETBIT(respKm11A->V1, 8)
           | SETBIT(respKm11A->J1, 3) | SETBIT(respKm11A->C1, 4) | SETBIT(respKm11A->T2, 5)
           | SETBIT(respKm11A->P1, 0) | SETBIT(respKm11A->L1, 1) | SETBIT(respKm11A->F1, 2);
    bupp = SETBIT(respKm11A->R1, 6) | SETBIT(respKm11A->K1, 7) | SETBIT(respKm11A->S2, 8)
           | SETBIT(respKm11A->S1, 3) | SETBIT(respKm11A->M2, 4) | SETBIT(respKm11A->F2, 5)
           | SETBIT(respKm11A->N2, 0) | SETBIT(respKm11A->D2, 1) | SETBIT(respKm11A->H2, 2);
    trap = SETBIT(respKm11A->D1, 0);
    ssyn = SETBIT(respKm11A->M1, 0);
    msyn = SETBIT(respKm11A->E1, 0);
    t = SETBIT(respKm11A->J2, 0);
    c = SETBIT(respKm11A->R2, 0);
    v = SETBIT(respKm11A->E2, 0);
    z = SETBIT(respKm11A->H1, 0);
    n = SETBIT(respKm11A->L2, 0);
}


void Pdp1140KM11AState::inputsToKM11AResponse(ResponseKM11Signals* respKm11A) {
    // get bits from state vars, different for all KM11s
    respKm11A->K2 = GETBIT(pupp, 6);
    respKm11A->N1 = GETBIT(pupp, 7);
    respKm11A->V1 = GETBIT(pupp, 8);
    respKm11A->P2 = 0;
    respKm11A->J1 = GETBIT(pupp, 3);
    respKm11A->C1 = GETBIT(pupp, 4);
    respKm11A->T2 = GETBIT(pupp, 5);
    respKm11A->U2 = 0;
    respKm11A->P1 = GETBIT(pupp, 0);
    respKm11A->L1 = GETBIT(pupp, 1);
    respKm11A->F1 = GETBIT(pupp, 2);
    respKm11A->R1 = GETBIT(bupp, 6);
    respKm11A->K1 = GETBIT(bupp, 7);
    respKm11A->S2 = GETBIT(bupp, 8);
    respKm11A->S1 = GETBIT(bupp, 3);
    respKm11A->M2 = GETBIT(bupp, 4);
    respKm11A->F2 = GETBIT(bupp, 5);
    respKm11A->N2 = GETBIT(bupp, 0);
    respKm11A->D2 = GETBIT(bupp, 1);
    respKm11A->H2 = GETBIT(bupp, 2);
    respKm11A->D1 = trap ;
    respKm11A->M1 = ssyn;
    respKm11A->E1 = msyn;
    respKm11A->J2 = t;
    respKm11A->R2 = c;
    respKm11A->E2 = v;
    respKm11A->H1 = z;
    respKm11A->L2 = n;

    // compose GPIOs from bits, same for all KM11s
    respKm11A->channel = 'A' ;
    respKm11A->setGpioValsFromFlipchipSignals();
}


void Pdp1140KM11BState::inputsFromKM11BResponse(ResponseKM11Signals* respKm11B)
{
    if (respKm11B->channel != 'B')
        LOGERROR("Pdp1140KM11Signals::inputsFromKM11B: channel B expected, is %c", respKm11B->channel);
    // let the compiler do all the demuxing
    respKm11B->getFlipchipSignalsFromGpioVals();

    pba = SETBIT(respKm11B->K2, 15) | SETBIT(respKm11B->N1, 16) | SETBIT(respKm11B->V1, 17)
          | SETBIT(respKm11B->J1, 12) | SETBIT(respKm11B->C1, 13) | SETBIT(respKm11B->T2, 14)
          | SETBIT(respKm11B->P1, 9) | SETBIT(respKm11B->L1, 10) | SETBIT(respKm11B->F1, 11)
          | SETBIT(respKm11B->R1, 6) | SETBIT(respKm11B->K1, 7) | SETBIT(respKm11B->S2, 8);
    rom_a = SETBIT(respKm11B->P2, 0);
    rom_b = SETBIT(respKm11B->U2, 0);
    rom_c = SETBIT(respKm11B->D1, 0);
    rom_d = SETBIT(respKm11B->M1, 0);
    b_15 = SETBIT(respKm11B->S1, 0);
    ecin_00 = SETBIT(respKm11B->M2, 0);
    exp_unfl = SETBIT(respKm11B->F2, 0);
    exp_ovfl = SETBIT(respKm11B->E1, 0);
    dr00 = SETBIT(respKm11B->N2, 0);
    dr09 = SETBIT(respKm11B->D2, 0);
    msr00 = SETBIT(respKm11B->H2, 0);
    msr01 = SETBIT(respKm11B->J2, 0);
    eps_c = SETBIT(respKm11B->R2, 0);
    eps_v = SETBIT(respKm11B->E2, 0);
    eps_z = SETBIT(respKm11B->H1, 0);
    eps_n = SETBIT(respKm11B->L2, 0);
}

void Pdp1140KM11BState::inputsToKM11BResponse(ResponseKM11Signals* respKm11B) {
	UNREFERENCED_PARAMETER(respKm11B) ;
    LOGERROR("Pdp1140KM11AState::inputsToKM11BResponse NOT YET IMPLEMENTED %s!", "");
}


void Pdp1140KM11AState::outputsToKM11AWriteRequest(RequestKM11SignalsWrite* reqKm11A)
{
    reqKm11A->channel = 'A';
    // Compare 11/40 KM11 overlay paper with "OUT" signals  in messages.txt
    // out00 = ---    out01 = MSTOP
    // out10 = MCLK   out11 = MCLK ENAB
    reqKm11A->A1 = 0;
    reqKm11A->B2 = mstop;
    reqKm11A->U1 = mclk; // "mclk_l" in fpms
    reqKm11A->V2 = mclk_enab; // "mclk_enab_l" in fpms
    reqKm11A->setVal03FromFlipchipSignals();
}

void Pdp1140KM11AState::outputsFromKM11AWriteRequest(RequestKM11SignalsWrite* reqKm11A) {
    reqKm11A->getFlipchipSignalsFromVal03();
    mstop = reqKm11A->B2 ;
    mclk = reqKm11A->U1 ; // "mclk_l" in fpms
    mclk_enab = reqKm11A->V2; // "mclk_enab_l" in fpms
}

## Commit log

2024-10-14 Autostepping brakes at MPC and UNIBUS fetch
2024-10-15 TraceController grid with extra empty row to compensate scroll problems
2024-10-15 tracegrid as CSV to clipboard
2024-11-09 fiddled with PDP11/40 KM11 wires and logic levels
2024-11-10 Fix of KM11 wiring out01 <-> out10
    [arduino.kicad_sch, km11.kicad_pcb]
2024-11-11 fix polarity of mclk and mclk_enab on write
    [pdp1140km11state.cpp]
2024-11-18 ^repalce synthetic KM11 signals "Inxx, out**" with flipchip pin names
    [M9302.kicad_sch, UNIBUS-Interface.kicad_sch, arduino.kicad_sch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]
2024-11-20 remove in**, out** silk, change to flipchip signals K2,P1,...
    [km11.kicad_pcb]
2024-11-20 pdp1140 simualotr sent double and wrong mpc, separeted 11/40 KM11 into KM11A and KM11B
    [pdp1140km11state.cpp]
2025-01-05 fix reichelt partnumbers
    [bom.ods]
2025-01-07 introduced uniform "stateVar" list, logic to display state changes in "trace" window
2025-01-09 part update
    [bom.ods]
2025-01-27 Big change: Scripting. Enhanced message flow (tags, function renaming), trace window (statevar change display)
2025-01-27 trace window: unibus cycles recveived correctly
2025-02-01 clearing trace in activity caused assertion
